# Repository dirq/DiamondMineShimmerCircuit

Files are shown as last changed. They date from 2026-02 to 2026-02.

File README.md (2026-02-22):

# Diamond Mine Shimmer Circuit — Final Design

A solar-charged, dusk-activated LED shimmer circuit. No microcontroller, no firmware —
pure analog CMOS logic and transistor drivers produce an organic, non-repeating sparkle
field that charges by day and shimmers by night.

## Documents

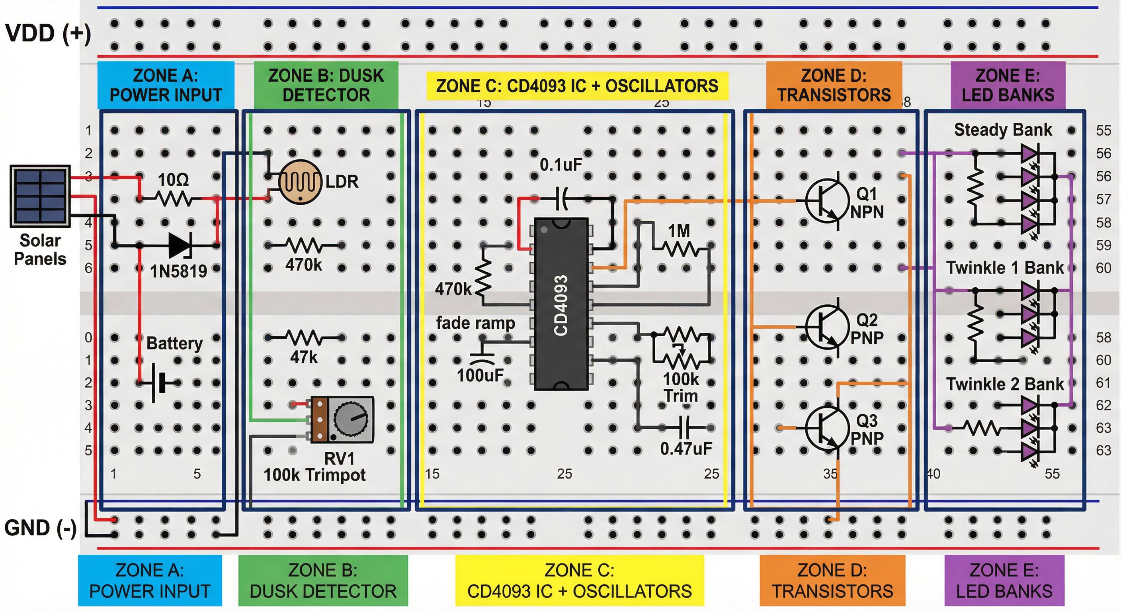
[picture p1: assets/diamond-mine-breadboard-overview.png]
Breadboard zone overview


| File | Contents |
|---|---|
| [BUILD-GUIDE.md](BUILD-GUIDE.md) | Step-by-step breadboard assembly and testing |
| [schematic.md](schematic.md) | Complete wiring schematic with gate assignments and net list |
| [bill-of-materials.md](bill-of-materials.md) | Full parts list with values, calculations, and cost |
| [breadboard-layout.md](breadboard-layout.md) | Physical layout with zone map and wire color guide |
| [circuit-evaluation.md](circuit-evaluation.md) | Performance characteristics and power budget |
| [circuit-evaluation-deep-dive.md](circuit-evaluation-deep-dive.md) | Extended design review with longevity analysis |
| [design-documentation.md](design-documentation.md) | Theory of operation, timing math, tuning guide |
| [bom.csv](bom.csv) | Machine-readable BOM for ordering |
| [diamond-mine-shimmer.cir](diamond-mine-shimmer.cir) | SPICE netlist for circuit simulation |
| [diamond-mine-shimmer.v](diamond-mine-shimmer.v) | Verilog behavioral model |
| [diamond-mine-shimmer.kicad_sch](diamond-mine-shimmer.kicad_sch) | KiCad schematic for PCB workflow |

## System Overview

```mermaid
graph TD
    subgraph Power
        SOLAR["Solar Panels<br/>5.5V, parallel"]
        RC["R_charge<br/>10 ohm"]
        D1["1N5819<br/>Schottky Diode"]
        BAT["3x AA NiMH<br/>3.6V nominal"]
        SOLAR -->|"charge"| RC --> D1 --> BAT
    end

    subgraph "CD4093 — Single IC, 4 Gates"
        G1["Gate 1<br/>Dusk Detector<br/>(pins 1,2 → 3)"]
        G2["Gate 2<br/>Oscillator 1 — Gated<br/>(pins 5,6 → 4)"]
        G3["Gate 3<br/>Oscillator 2 — Gated<br/>(pins 8,9 → 10)"]
        G4["Gate 4<br/>Unused — tied to VDD<br/>(pins 12,13 → 11)"]
    end

    subgraph Sensing
        LDR["LDR + Resistor<br/>Voltage Divider"]
        FADE["Fade-In Ramp<br/>470k + 100uF<br/>τ = 47s"]
    end

    subgraph "LED Outputs"
        Q1["Q1 (NPN 2N3904)<br/>Steady Bank<br/>3x LED @ 1.5k"]
        Q2["Q2 (PNP 2N3906)<br/>Twinkle Bank 1<br/>3x LED @ 2.2k"]
        Q3["Q3 (PNP 2N3906)<br/>Twinkle Bank 2<br/>3x LED @ 2.2k"]
    end

    BAT -->|"VDD"| G1
    BAT -->|"VDD"| G2
    BAT -->|"VDD"| G3
    LDR -->|"SENSE"| G1
    G1 -->|"DARK signal"| FADE
    G1 -->|"DARK gates pin 5"| G2
    G1 -->|"DARK gates pin 8"| G3
    FADE -->|"ramp voltage"| Q1
    G2 -->|"~2.6 Hz square wave"| Q2
    G3 -->|"~2.4 Hz square wave"| Q3
```

## Signal Flow at Dusk

```mermaid
sequenceDiagram
    participant Light as Ambient Light
    participant LDR as LDR Sensor
    participant G1 as Gate 1 (Dusk)
    participant Fade as Fade Ramp
    participant Osc as Oscillators
    participant LEDs as LED Field

    Light->>LDR: Light level drops
    LDR->>G1: SENSE voltage falls below VT-
    G1->>G1: Schmitt hysteresis prevents flicker
    G1->>Fade: DARK goes HIGH
    G1->>Osc: DARK enables Gate 2 and Gate 3
    Fade->>LEDs: Steady bank glows (10s to start, 40s full)
    Osc->>LEDs: Twinkle banks shimmer at ~2.4–2.6 Hz
    Note over LEDs: Beat frequency ~0.2 Hz creates<br/>drifting 5-second visual pattern
```

## Design Highlights

- **Solar self-sufficiency** — 5.5V panels with current-limited trickle charge
- **Smooth dusk activation** — Schmitt hysteresis prevents twilight flicker
- **Gentle 40-second fade-in** — RC ramp creates organic bloom
- **Multi-layer shimmer** — dual oscillator beats produce non-repeating patterns
- **Correct day/night gating** — PNP high-side switches ensure zero LED current in daylight
- **~5 mA active / ~7 uA standby** — months of battery life, easily solar-sustained
- **No microcontroller, no regulator, no firmware**

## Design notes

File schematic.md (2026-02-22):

# Wiring Schematic — Diamond Mine Shimmer

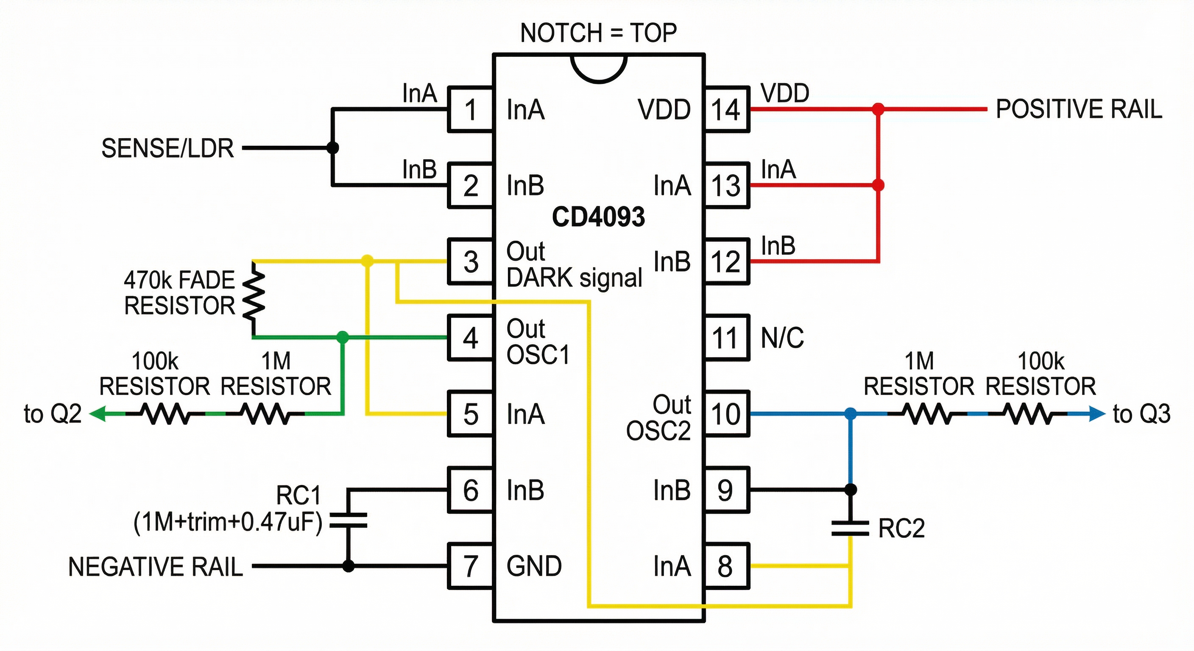
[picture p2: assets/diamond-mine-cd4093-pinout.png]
CD4093 pinout and connections


## CD4093 Pin Assignment

```
              ┌────∪────┐
Gate1 InA  1 ─┤         ├─ 14  VDD (+3.6V)
Gate1 InB  2 ─┤         ├─ 13  Gate4 InA (→ VDD)
Gate1 Out  3 ─┤  CD4093 ├─ 12  Gate4 InB (→ VDD)
Gate2 Out  4 ─┤         ├─ 11  Gate4 Out  (N/C)
Gate2 InA  5 ─┤         ├─ 10  Gate3 Out
Gate2 InB  6 ─┤         ├─  9  Gate3 InB
      GND  7 ─┤         ├─  8  Gate3 InA
              └─────────┘
```

```mermaid
graph TD
    subgraph "CD4093 Gate Assignments"
        direction LR
        G1["Gate 1 — Dusk Detector<br/>Pin 1 + Pin 2 → Pin 3<br/>(both inputs tied = inverter)"]
        G2["Gate 2 — Oscillator 1<br/>Pin 5 (DARK) + Pin 6 (RC) → Pin 4<br/>(gated oscillator)"]
        G3["Gate 3 — Oscillator 2<br/>Pin 8 (DARK) + Pin 9 (RC) → Pin 10<br/>(gated oscillator)"]
        G4["Gate 4 — Unused<br/>Pin 12 + Pin 13 → Pin 11<br/>(inputs tied to VDD)"]
    end
```

---

## Section A: Power and Charging

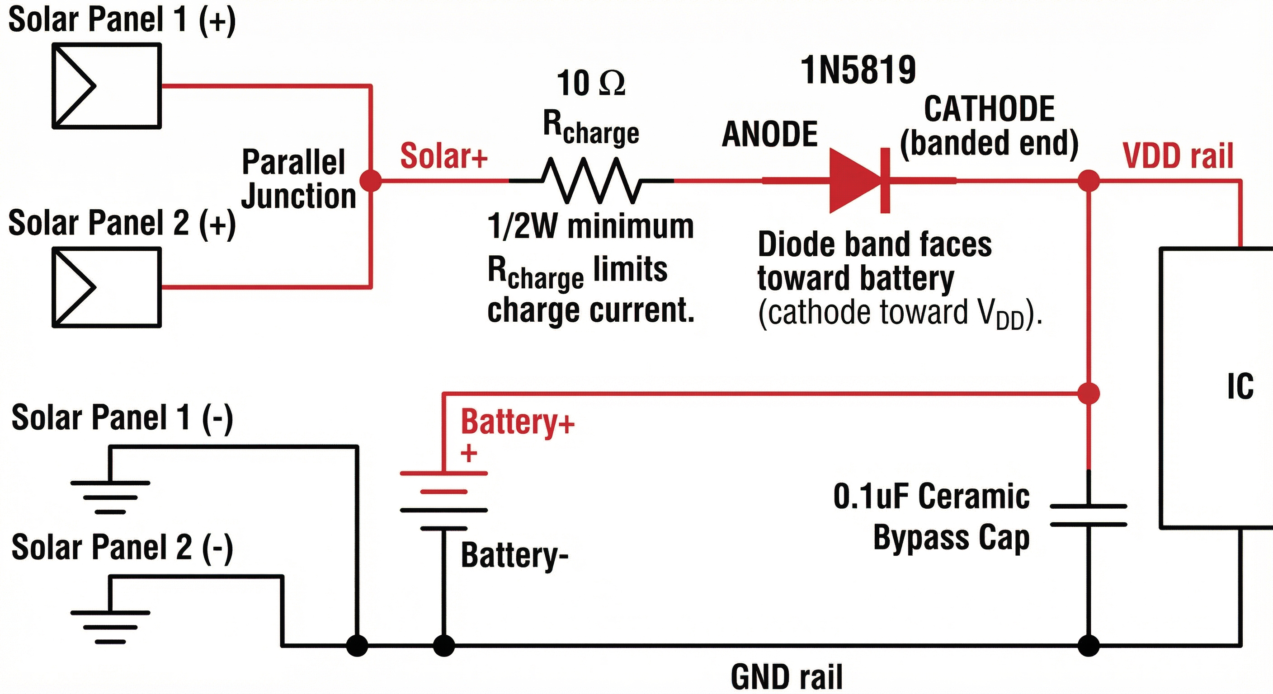
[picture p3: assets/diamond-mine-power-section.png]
Power section — solar, R_charge, diode, battery


```
    Solar+ ── R_charge (10Ω) ──┤>├──────── Battery+ (VDD)
                              1N5819
    Solar- ──────────────────────────────── Battery- (GND)

    Battery: 3x AA NiMH in series = 3.6V nominal
    Solar panels: 5.5V, 80–100 mA each, wired in parallel
    R_charge limits trickle current to safe NiMH range (85–220 mA)

    Bypass cap (close to IC pins):
    VDD (pin 14) ───┤├─── GND (pin 7)
                   0.1uF ceramic
```

```mermaid
graph LR
    S1["Solar Panel 1<br/>5.5V"] --> P["Parallel Junction"]
    S2["Solar Panel 2<br/>5.5V"] --> P
    P -->|"Solar+"| RC["R_charge<br/>10 ohm 1/2W"]
    RC --> D["1N5819<br/>Schottky"]
    D -->|"VDD"| B["+<br/>3x AA NiMH<br/>3.6V<br/>-"]
    B -->|"GND"| GND["System Ground"]
    D -->|"VDD"| C["0.1uF<br/>bypass"]
    C --> GND
```

---

## Section B: Dusk Detector (Gate 1)

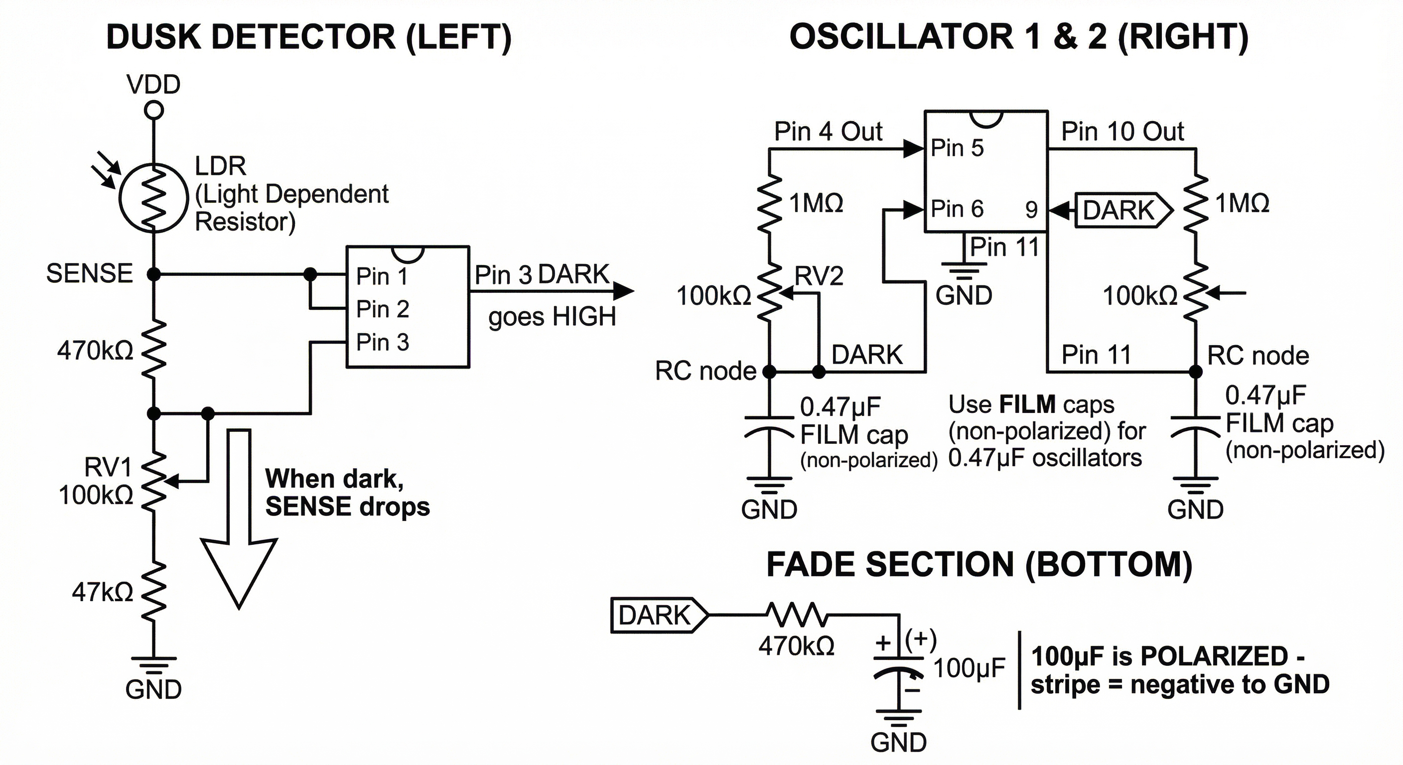
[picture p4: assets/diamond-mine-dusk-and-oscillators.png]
Dusk detector, fade ramp, and oscillator RC networks


```
    VDD ─── LDR ───┬─── Pin 1 (Gate1 InA)
                    │
                    ├─── Pin 2 (Gate1 InB)
                    │
                    └── 470k ──┬── 100k trimpot ── GND
                               │
                               └── 47k ── GND

    Pin 3 (Gate1 Out) = DARK signal
      Bright → LDR low-R → SENSE high → Output LOW  → LEDs OFF
      Dark   → LDR high-R → SENSE low → Output HIGH → LEDs ON
```

```mermaid
graph TD
    VDD["VDD (+3.6V)"] --> LDR["LDR<br/>(light dependent resistor)"]
    LDR --> SENSE["SENSE node"]
    SENSE --> P1["Pin 1"]
    SENSE --> P2["Pin 2"]
    SENSE --> R470["470k fixed"]
    R470 --> RNODE["Threshold junction"]
    RNODE --> TRIM["100k trimpot"]
    TRIM --> GND["GND"]
    RNODE --> R47["47k fixed"]
    R47 --> GND
    P1 --> G1["Gate 1 Output<br/>Pin 3"]
    P2 --> G1
    G1 --> DARK["DARK signal"]

    style DARK fill:#ffcc00,color:#000
```

---

## Section C: Fade-In Ramp

```
    Pin 3 (DARK) ── 470k ──┬── FADE node
                            │
                          100uF electrolytic
                            │
                           GND

    τ = 470k x 100uF = 47 seconds
    LEDs begin glowing at ~10s (Vbe threshold)
    Full brightness at ~40s
```

```mermaid
graph LR
    DARK["Pin 3<br/>DARK"] -->|"470k"| FADE["FADE node"]
    FADE -->|"100uF"| GND["GND"]
    FADE -->|"10k"| Q1B["Q1 Base<br/>(NPN Steady Bank)"]

    style DARK fill:#ffcc00,color:#000
    style FADE fill:#ff9944,color:#000
```

---

## Section D: Oscillator 1 — Gated (Gate 2)

```
    Pin 5 (Gate2 InA) ──── Pin 3 (DARK signal)     ← gating input

    Pin 4 (Gate2 Out) ── 1M ── 100k trimpot ──┬── Pin 6 (Gate2 InB)
                                               │
                                             0.47uF film
                                               │
                                              GND

    DARK=LOW  → Output stuck HIGH, no oscillation
               PNP transistor OFF → zero LED current
    DARK=HIGH → Oscillates at ~2.4–2.6 Hz (adjustable via trimpot)
               PNP transistor toggles → LEDs shimmer
```

---

## Section E: Oscillator 2 — Gated (Gate 3)

```
    Pin 8 (Gate3 InA) ──── Pin 3 (DARK signal)     ← gating input

    Pin 10 (Gate3 Out) ── 1M ── 100k trimpot ──┬── Pin 9 (Gate3 InB)
                                                │
                                              0.47uF film
                                                │
                                               GND

    Set trimpot to different position than Osc 1 for beat-frequency shimmer
```

```mermaid
graph TD
    DARK["DARK signal<br/>(Pin 3)"] --> P5["Pin 5<br/>(Gate 2 InA)"]
    DARK --> P8["Pin 8<br/>(Gate 3 InA)"]

    P4["Pin 4<br/>(Gate 2 Out)"] -->|"1M + 100k trim"| RC1["RC Node 1"]
    RC1 --> P6["Pin 6<br/>(Gate 2 InB)"]
    RC1 -->|"0.47uF"| GND1["GND"]
    P5 --- G2{"Gate 2"}
    P6 --- G2
    G2 --> P4

    P10["Pin 10<br/>(Gate 3 Out)"] -->|"1M + 100k trim"| RC2["RC Node 2"]
    RC2 --> P9["Pin 9<br/>(Gate 3 InB)"]
    RC2 -->|"0.47uF"| GND2["GND"]
    P8 --- G3{"Gate 3"}
    P9 --- G3
    G3 --> P10

    style DARK fill:#ffcc00,color:#000
```

**Frequency range with 1M fixed + 100k trimpot + 0.47uF:**

| Trimpot setting | Total R | Frequency | Character |
|---|---|---|---|
| 0 ohm (min) | 1.0M | 2.6 Hz | Quick shimmer |
| 50k (mid) | 1.05M | 2.5 Hz | Medium shimmer |
| 100k (max) | 1.1M | 2.4 Hz | Slightly slower |

---

## Section F: Unused Gate 4

```
    Pin 12 (Gate4 InA) ──── VDD
    Pin 13 (Gate4 InB) ──── VDD
    Pin 11 (Gate4 Out)      no connection
```

Floating CMOS inputs draw excess current and risk latch-up. Always tie unused
inputs to a rail.

---

## Section G: LED Drivers

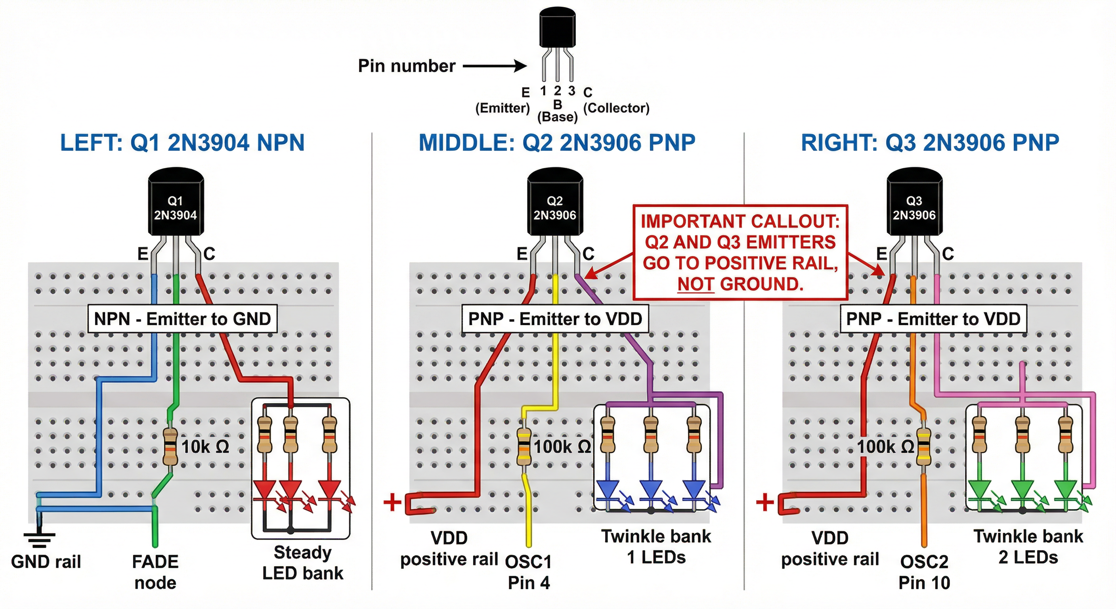
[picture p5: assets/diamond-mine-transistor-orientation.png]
Transistor orientation — E-B-C pin order, NPN vs PNP


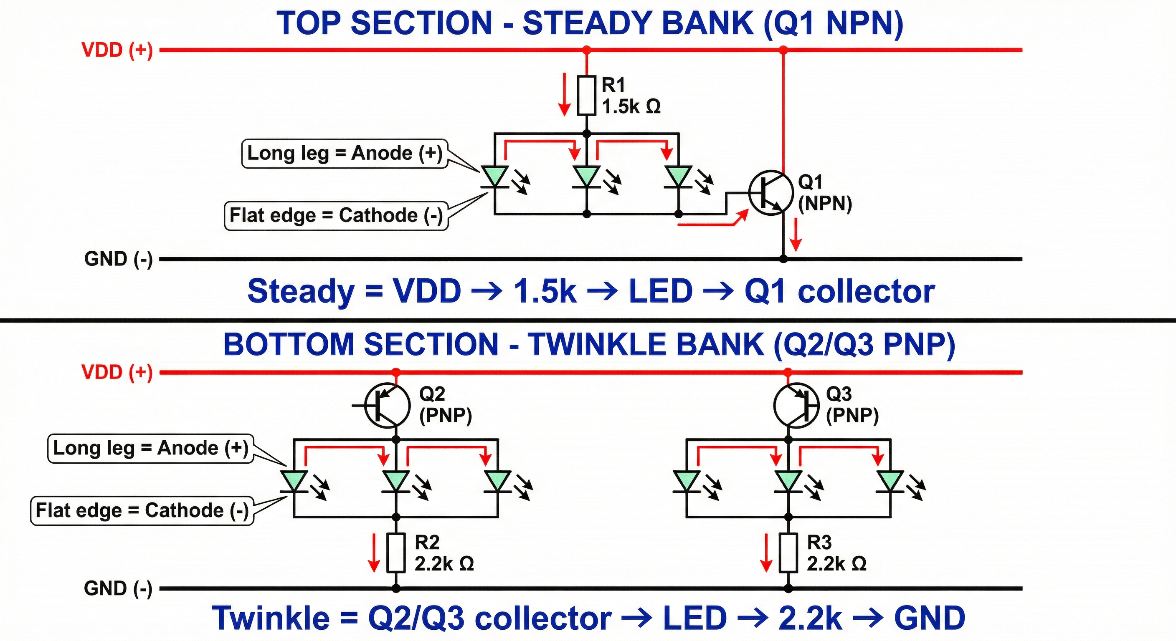
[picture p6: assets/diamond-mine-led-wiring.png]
LED wiring — Steady bank vs Twinkle bank topology


### Steady Bank — Q1 (NPN 2N3904, low-side switch, fade-controlled)

```
    FADE node ── 10k ──── Q1 Base (2N3904 NPN)
                          Q1 Emitter ── GND
                          Q1 Collector ──┬── LED1 cathode ── LED1 anode ── 1.5k ── VDD
                                         ├── LED2 cathode ── LED2 anode ── 1.5k ── VDD
                                         └── LED3 cathode ── LED3 anode ── 1.5k ── VDD
```

Day: FADE = 0V → Q1 OFF → LEDs dark
Night: FADE ramps 0V → 3.6V over 47s → Q1 gradually turns on → LEDs bloom

### Twinkle Bank 1 — Q2 (PNP 2N3906, high-side switch)

```
                          VDD
                           │
                       Q2 Emitter (2N3906 PNP)
                           │
    Pin 4 (OSC1) ── 100k ── Q2 Base
                           │
                       Q2 Collector ──┬── LED anode ── LED cathode ── 2.2k ── GND
                                      ├── LED anode ── LED cathode ── 2.2k ── GND
                                      └── LED anode ── LED cathode ── 2.2k ── GND
```

Day: Pin 4 = HIGH (stuck) → Q2 base ≈ VDD → Veb ≈ 0 → Q2 OFF → LEDs dark
Night: Pin 4 oscillates → Q2 toggles → LEDs shimmer

### Twinkle Bank 2 — Q3 (PNP 2N3906, high-side switch)

```
                          VDD
                           │
                       Q3 Emitter (2N3906 PNP)
                           │
    Pin 10 (OSC2) ── 100k ── Q3 Base
                           │
                       Q3 Collector ──┬── LED anode ── LED cathode ── 2.2k ── GND
                                      ├── LED anode ── LED cathode ── 2.2k ── GND
                                      └── LED anode ── LED cathode ── 2.2k ── GND
```

```mermaid
graph TD
    VDD["VDD (+3.6V)"]

    VDD -->|"1.5k"| SL1["LED"] --> Q1C["Q1 Collector"]
    VDD -->|"1.5k"| SL2["LED"] --> Q1C
    VDD -->|"1.5k"| SL3["LED"] --> Q1C
    FADE["FADE node"] -->|"10k"| Q1B["Q1 Base"]
    Q1B --> Q1["Q1 NPN<br/>2N3904"]
    Q1C --> Q1
    Q1 --> GND1["GND"]

    VDD --> Q2E["Q2 Emitter"]
    Q2E --> Q2["Q2 PNP<br/>2N3906"]
    OSC1["Pin 4<br/>OSC1"] -->|"100k"| Q2B["Q2 Base"]
    Q2B --> Q2
    Q2 --> Q2C["Q2 Collector"]
    Q2C --> TL1["LED"] -->|"2.2k"| GND2["GND"]
    Q2C --> TL2["LED"] -->|"2.2k"| GND2
    Q2C --> TL3["LED"] -->|"2.2k"| GND2

    VDD --> Q3E["Q3 Emitter"]
    Q3E --> Q3["Q3 PNP<br/>2N3906"]
    OSC2["Pin 10<br/>OSC2"] -->|"100k"| Q3B["Q3 Base"]
    Q3B --> Q3
    Q3 --> Q3C["Q3 Collector"]
    Q3C --> TL4["LED"] -->|"2.2k"| GND3["GND"]
    Q3C --> TL5["LED"] -->|"2.2k"| GND3
    Q3C --> TL6["LED"] -->|"2.2k"| GND3

    style FADE fill:#ff9944,color:#000
    style OSC1 fill:#44cc44,color:#000
    style OSC2 fill:#4488ff,color:#fff
```

---

## Complete Net List

| Net Name | Connections |
|---|---|
| **VDD** | Battery+, R_charge output, Pin 14, Pin 12, Pin 13, LDR leg 1, Steady LED anode resistors, Q2 emitter, Q3 emitter, 0.1uF cap |
| **GND** | Battery-, Pin 7, Trimpot/47k ground ends, 100uF(-), 0.47uF(x2), Q1 emitter, Twinkle LED cathode resistors, 0.1uF cap |
| **SOLAR+** | Solar panel positive bus, R_charge input |
| **CHARGE** | R_charge output, 1N5819 anode |
| **SENSE** | LDR leg 2, Pin 1, Pin 2, 470k top |
| **THRESH** | 470k bottom, 100k trimpot wiper/end1, 47k top |
| **DARK** | Pin 3, Pin 5, Pin 8, 470k fade top |
| **FADE** | 470k fade bottom, 100uF(+), 10k top |
| **RC1** | 1M+trim/0.47uF junction (osc 1), Pin 6 |
| **RC2** | 1M+trim/0.47uF junction (osc 2), Pin 9 |
| **OSC1** | Pin 4, 1M top (to RC1), 100k (to Q2 base) |
| **OSC2** | Pin 10, 1M top (to RC2), 100k (to Q3 base) |
| **Q1_COL** | Q1 collector, Steady LED cathodes (3x) |
| **Q2_COL** | Q2 collector, Twinkle 1 LED anodes (3x) |
| **Q3_COL** | Q3 collector, Twinkle 2 LED anodes (3x) |

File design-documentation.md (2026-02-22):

# Design Documentation — Diamond Mine Shimmer Circuit

## 1. Design Philosophy

The goal is a self-sustaining "bioluminescent cave" — something that feels alive
without any digital intelligence. Every design choice serves this:

- **No microcontroller**: Analog randomness is inherently organic. Two free-running
  oscillators with irrational frequency ratios produce quasi-random patterns that
  never exactly repeat.
- **Solar + NiMH**: The circuit runs itself indefinitely with zero user intervention.
- **CMOS logic at 3.6V**: The CD4093 operates down to 3V with nanoamp-level
  quiescent current — perfect for battery life.
- **Schmitt-trigger hysteresis**: Prevents chatter at the dusk/dawn boundary and
  creates clean oscillator waveforms.
- **PNP high-side twinkle switches**: Ensures zero LED current during daytime when
  the NAND gate outputs are stuck HIGH.

---

## 2. Power System

### 2.1 Solar Charging

```
Solar Panels (5.5V, parallel) ── R_charge (10Ω) ──►|── 3×AA NiMH (3.6V)
                                                   1N5819
```

**Why 5.5V panels?** The battery pack reaches 4.35V when fully charged. Adding
the Schottky drop (0.3V), the solar source must exceed 4.65V. Panels rated at
5.5V provide adequate headroom across all conditions.

**Why parallel wiring?** Parallel panels produce the same voltage at combined
current. Series wiring would give 11V — far too high for direct NiMH charging
without a regulator.

**Why R_charge (10 ohm)?** Without current limiting, a fully discharged battery
could draw the panel's full short-circuit current. The resistor self-tapers
the charge rate:

| Battery State | Voltage | Charge Current | Rate |
|---|---|---|---|
| Deeply discharged | 3.0V | 220 mA | C/9 |
| Nominal | 3.6V | 160 mA | C/12.5 |
| Near full | 4.0V | 120 mA | C/17 |
| Fully charged | 4.35V | 85 mA | C/24 |

NiMH cells safely tolerate indefinite trickle at C/10 or below. The resistor
keeps the circuit in the safe zone for all practical conditions.

**Why Schottky?** At night, solar panels become low-impedance paths to ground.
Without D1, the battery discharges backward through the panels. A standard
silicon diode (1N4001) drops ~0.6V — at 3.6V that is a 17% loss. The 1N5819
Schottky drops only ~0.3V.

**Why NiMH?** NiMH cells tolerate continuous trickle charging without a charge
controller (unlike Li-ion). At the C/24 rates typical of this design at full
charge, they charge safely and indefinitely. Eneloop cells provide 2100-cycle
life and <15% self-discharge over 6 months.

### 2.2 Battery Sizing

Three NiMH cells give 3.6V nominal (3.0V discharged, 4.35V freshly charged).
This keeps the CD4093 comfortably in its 3–18V operating range and provides
enough headroom above red/amber LED forward voltage (~1.8–2.1V).

---

## 3. Dusk Detector

```
VDD ──── [LDR] ──── SENSE ──┬── [470k] ──┬── [100k trimpot] ── GND
                             │            └── [47k] ── GND
                        CD4093 Gate 1
                        (pins 1+2 tied)
```

### 3.1 Voltage Divider Behavior

| Condition | LDR Resistance | SENSE Voltage | Gate 1 Output |
|---|---|---|---|
| Bright light | ~5–10 kΩ | High (~VDD) | LOW (disabled) |
| Dim indoor | ~100–500 kΩ | Mid | Depends on trimpot |
| Darkness | ~500 kΩ–2 MΩ | Low (~GND) | HIGH (enabled) |

### 3.2 Pull-Down Network

The three-element pull-down (470k fixed + 100k trimpot || 47k) provides:

With trimpot at 0Ω: pull-down = 470k + (0 || 47k) = 470k
With trimpot at 100k: pull-down = 470k + (100k || 47k) = 470k + 32k = 502k

The trimpot provides fine adjustment (~7% range) rather than coarse control.
This is appropriate for a set-once installation.

### 3.3 Schmitt-Trigger Advantage

The CD4093 has built-in hysteresis (~30% of VDD). At 3.6V:
- Upper threshold (VT+): ~2.4V
- Lower threshold (VT-): ~1.2V
- Hysteresis band: ~1.2V

This prevents rapid on/off cycling during gradual dusk transitions. The SENSE
voltage must cross VT- (falling) to turn LEDs on, and VT+ (rising) to turn
them off. The ~1.2V gap means the LDR must change by hundreds of kilohms
between the two states — ensuring clean, single transitions.

---

## 4. Fade-In Ramp

```
DARK (HIGH) ──── [470kΩ] ──── FADE ──┬──── [100µF] ──── GND
                                      │
                                      └── [10k] → Q1 base
```

### 4.1 RC Time Constant

```
τ = R × C = 470,000 Ω × 0.0001 F = 47 seconds
```

### 4.2 Voltage Profile

```
V_FADE(t) = V_DARK × (1 - e^(-t/τ))
```

| Time | V_FADE | % of V_DARK | Perceived Effect |
|---|---|---|---|
| 0 s | 0.00V | 0% | LEDs off |
| 10 s | 0.72V | 19% | First hint of glow (Vbe threshold) |
| 20 s | 1.21V | 34% | Visible dim glow |
| 47 s | 2.27V | 63% | Moderate brightness (1τ) |
| 94 s | 3.10V | 86% | Near full (2τ) |
| 141 s | 3.42V | 95% | Essentially full (3τ) |

Q1 operates in its active (linear) region during the ramp, so LED current
rises proportionally with V_FADE. The visual effect is a smooth, organic bloom.

### 4.3 Dawn Fade-Out

When DARK goes LOW at dawn:
1. The 100uF cap discharges through 10k into Q1 base (τ = 1s) while Q1 conducts
2. LEDs fade out in ~2–3 seconds
3. Below Vbe (~0.7V), Q1 turns off and remaining charge bleeds through 470k

The fade-out is fast but not jarring — an appropriate "lights going to sleep"
transition.

### 4.4 Modification Options

| Desired Fade Time | R_fade | τ (seconds) | 95% Time |
|---|---|---|---|
| Quick (10 s) | 100 kΩ | 10 s | ~30 s |
| Medium (47 s) | 470 kΩ | 47 s | ~2.5 min |
| Slow (100 s) | 1 MΩ | 100 s | ~5 min |
| Very slow (220 s) | 2.2 MΩ | 220 s | ~11 min |

---

## 5. Schmitt-Trigger Oscillators

Each oscillator is a classic CD4093 relaxation oscillator with gating:

```
    DARK ──── Pin 5 (Gate 2 InA)         ← gating input

         ┌──── [R_osc (1MΩ + Trim)] ────┐
         │                                │
    Pin 6 (InB) ──────────────── Pin 4 (Out)
         │
      [C_osc 0.47µF]
         │
        GND
```

### 5.1 How It Works

1. When DARK = HIGH, the gate acts as an inverter on Pin 6.
2. Capacitor charges through R_osc toward VDD.
3. When voltage crosses the **upper Schmitt threshold** (~2.4V), the output snaps LOW.
4. Capacitor discharges through R_osc toward GND.
5. When voltage crosses the **lower Schmitt threshold** (~1.2V), the output snaps HIGH.
6. Cycle repeats.

When DARK = LOW, the NAND output is stuck HIGH regardless of Pin 6. No
oscillation occurs.

### 5.2 Frequency Formula

```
f ≈ 1 / (1.2 × R × C)
```

For R = 1.05MΩ (1M + 50k trim) and C = 0.47µF:
```
f ≈ 1 / (1.2 × 1,050,000 × 0.00000047)
f ≈ 1 / 0.592
f ≈ 1.69 Hz  (theoretical)
```

Actual frequency is typically 2.4–2.6 Hz due to Schmitt threshold ratios differing
from the 1.2x approximation at low VDD. The trimpot allows fine adjustment.

### 5.3 Frequency Range

| Trimpot Setting | Total R | Frequency | Character |
|---|---|---|---|
| 0 ohm (min) | 1.0M | ~2.6 Hz | Quick shimmer |
| 50k (mid) | 1.05M | ~2.5 Hz | Medium shimmer |
| 100k (max) | 1.1M | ~2.4 Hz | Slightly slower |

### 5.4 The Shimmer Effect

The magic happens because the two oscillators run at **slightly different
frequencies**. If Osc 1 runs at 2.6 Hz and Osc 2 at 2.4 Hz, the beat frequency is:

```
f_beat = |f1 - f2| = |2.6 - 2.4| = 0.2 Hz → 5-second drift cycle
```

The steady-glow bank provides a constant "floor" while the two twinkle banks
create overlapping shimmer. Together, the three layers produce a complex,
organic light field:

```
Brightness
    ▲
    │   ╱╲   ╱╲   ╱╲   ╱╲       ← Twinkle Bank 1 (~2.6 Hz)
    │  ╱  ╲ ╱  ╲ ╱  ╲ ╱  ╲
    │──────────────────────────  ← Steady Glow (base)
    │    ╱╲  ╱╲  ╱╲  ╱╲
    │   ╱  ╲╱  ╲╱  ╲╱  ╲       ← Twinkle Bank 2 (~2.4 Hz)
    │
    └──────────────────────────► Time
           ↕ 5s beat cycle ↕
```

---

## 6. LED Driver Design

### 6.1 Q1: Steady Bank (NPN 2N3904, Low-Side)

```
VDD ──── [1.5k] ──── LED ──── Q1 Collector
                               Q1 Emitter ── GND
FADE ──── [10k] ──── Q1 Base
```

During fade-in, Q1 operates in its **active region** — collector current rises
proportionally with base voltage. Once V_FADE reaches full VDD, Q1 saturates and
LED current is limited by the 1.5k resistor:

```
I_LED = (VDD - V_LED - Vce_sat) / R = (3.6 - 2.0 - 0.2) / 1500 = 0.93 mA
```

### 6.2 Q2/Q3: Twinkle Banks (PNP 2N3906, High-Side)

```
                   VDD
                    │
                Q2 Emitter (PNP)
                    │
OSC1 ── [100k] ── Q2 Base
                    │
                Q2 Collector
                    │
                   LED
                    │
                  [2.2k]
                    │
                   GND
```

**Why PNP high-side?** The oscillator NAND gates output HIGH when DARK = LOW
(daytime). With NPN low-side switches, this HIGH would turn the transistors ON —
keeping twinkle LEDs lit during the day. PNP transistors turn OFF when their
base is at VDD (HIGH), solving this naturally:

| Oscillator Output | PNP Base | PNP State | LEDs |
|---|---|---|---|
| HIGH (day, stuck) | ≈ VDD | OFF (Veb ≈ 0) | Dark |
| HIGH (night, osc) | ≈ VDD | OFF | Dark |
| LOW (night, osc) | ≈ 0V | ON (Veb ≈ VDD) | Lit |

Base drive through 100k ensures reliable saturation for 3 LEDs per bank:
```
Ib = (VDD - Vbe) / 100k = (3.6 - 0.7) / 100k = 29 uA
Ic_max = hFE × Ib = 100 × 29 uA = 2.9 mA (> 1.92 mA needed)
```

LED current when ON:
```
I_LED = (VDD - Vce_sat - V_LED) / R = (3.6 - 0.2 - 2.0) / 2200 = 0.64 mA
```

### 6.3 Why Individual LED Resistors?

Each LED has manufacturing variations in forward voltage (±0.2V typical). With
a shared resistor, the lowest-Vf LED hogs current while others go dim. Individual
resistors ensure equal current sharing — critical for visual uniformity in the
"diamond field."

---

## 7. Component Selection Rationale

### CD4093 (not CD4011)

The Schmitt-trigger inputs provide:
1. **Clean oscillation** — defined thresholds prevent erratic behavior
2. **Noise immunity** — ~1.2V hysteresis rejects power supply ripple
3. **Reliable dusk switching** — clean snap despite slowly-changing LDR voltage

### 2N3906 PNP (not 2N3904 NPN) for Twinkle Banks

NAND gate with one LOW input gives HIGH output. For zero daytime current:
- NPN + HIGH output = ON (wrong)
- PNP + HIGH output = OFF (correct)

### Film Capacitors (not ceramic) for Oscillators

Film capacitors have:
- Tight tolerance (±5% vs ±20% for ceramic)
- Zero piezoelectric effect
- Excellent long-term stability
- Negligible leakage

For timing, this means twinkle rate stays consistent over temperature and years.

### Red/Amber LEDs (not white/blue)

At 3.6V supply with 2.2k resistors:
- Red/amber (Vf ~2.0V): I = (3.6-0.2-2.0)/2200 = 0.64 mA (bright enough)
- White/blue (Vf ~3.0V): I = (3.6-0.2-3.0)/2200 = 0.18 mA (very dim)

Red and amber also evoke the warm "crystal mine" aesthetic.

---

## 8. Power Budget

### 8.1 Standby (Daytime)

| Component | Current |
|---|---|
| CD4093 quiescent (static) | ~0.005 µA |
| LDR divider (bright: ~5k + ~500k) | ~7 µA |
| Q1 OFF (FADE = 0V) | 0 |
| Q2/Q3 OFF (PNP, base HIGH) | 0 |
| **Total standby** | **~7 µA** |

### 8.2 Active (Nighttime)

| Component | Current |
|---|---|
| CD4093 + oscillators (dynamic) | ~0.1 mA |
| LDR divider (dark) | ~2.4 µA |
| Steady bank: 3 × 0.93 mA | 2.79 mA |
| Twinkle 1: 3 × 0.64 mA × 50% | 0.96 mA |
| Twinkle 2: 3 × 0.64 mA × 50% | 0.96 mA |
| Q1 base drive | 0.29 mA |
| Q2/Q3 base drive | 0.06 mA |
| **Total active (average)** | **~5.1 mA** |
| **Total active (peak)** | **~7.0 mA** |

### 8.3 Battery Life

```
Without solar:
  Continuous: 2000 / 5.1 = 392 hours ≈ 16.3 days
  10 hrs/night: 39 nights

With solar (2 panels, 4 hrs sun):
  Daily charge: 200 mA × 4 hrs = 800 mAh
  Daily discharge: 5.1 mA × 10 hrs = 51 mAh
  Net surplus: +749 mAh/day → battery stays full indefinitely
```

---

## 9. Tuning Guide

### 9.1 Dusk Sensitivity (RV1)

Turn the 100k dusk trimpot:
- **Clockwise** (more resistance): triggers at slightly less darkness
- **Counter-clockwise** (less resistance): requires deeper darkness

Test by slowly covering the LDR and observing when the DARK signal goes HIGH
(measure Pin 3 with a multimeter).

### 9.2 Twinkle Rates (RV2, RV3)

Set each oscillator's trimpot to a different position:
- Both at similar settings: synchronized flashing (less interesting)
- Slightly different: slow beat pattern (optimal shimmer)
- Very different: fast, complex pattern

**Recommended starting point:** RV2 at 30%, RV3 at 70%. This gives a beat
period of about 5 seconds — a gentle, natural-feeling drift.

### 9.3 Fade Speed

The fade-in time is set by R_fade (470k) and C_fade (100uF). To change:
- Faster: replace R_fade with 220k (τ ≈ 22s)
- Slower: replace R_fade with 1M (τ ≈ 100s)

### 9.4 LED Brightness

| Change | Method | Effect |
|---|---|---|
| Brighter steady | Reduce 1.5k to 680Ω | ~2.1 mA per LED |
| Dimmer steady | Increase 1.5k to 3.3k | ~0.42 mA per LED |
| Brighter twinkle | Reduce 2.2k to 1k | ~1.4 mA per LED |
| Dimmer twinkle | Increase 2.2k to 4.7k | ~0.30 mA per LED |
| More LEDs | Add LEDs to any bank | Scale resistor count to match |
| Mixed colors | Use different Vf LEDs | Adjust resistors per-LED for equal brightness |

---

## 10. Advanced Modifications

### 10.1 Third Oscillator (Gate 4)

Gate 4 is currently unused. Wire it as a third oscillator for an additional
shimmer layer:

- **Slow breathing (0.2 Hz):** 1M + 2.2µF → drives another PNP + LED cluster
- **Fast glitter (8–10 Hz):** 220k + 0.47µF → subtle high-speed sparkle overlay

### 10.2 PWM Dimming via Gate Mixing

Use Gate 4 as an AND/OR combiner of the two oscillator outputs. The resulting
complex waveform drives a single LED bank through a PNP transistor, creating
pulse patterns impossible with a single oscillator.

### 10.3 Solar Panel Voltage Indicator

Add a single LED + 100kΩ from the solar panel positive (before R_charge) to
GND. It glows faintly during daylight to confirm panels are producing power.
Current: (5.5 - 2.0) / 100k = 35µA — negligible impact on charging.

### 10.4 Under-Voltage Lockout

For extra NiMH protection, add a TL431 or MAX809 voltage supervisor ($0.50)
that disables the circuit below 3.0V. This prevents deep discharge damage
during extended cloudy periods.

---

## 11. References

- CD4093 datasheet: [Texas Instruments CD4093B](https://www.ti.com/product/CD4093B)
- 2N3904 datasheet: [ON Semiconductor 2N3904](https://www.onsemi.com/pdf/datasheet/2n3904-d.pdf)
- 2N3906 datasheet: [ON Semiconductor 2N3906](https://www.onsemi.com/pdf/datasheet/2n3906-d.pdf)
- 1N5819 datasheet: [Vishay 1N5819](https://www.vishay.com/docs/88526/1n5819.pdf)
- NiMH charging guide: [Battery University — NiMH](https://batteryuniversity.com/article/bu-407-charging-nickel-metal-hydride)

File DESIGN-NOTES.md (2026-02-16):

# Design Notes

> Circuit theory, timing math, and tuning guidance for the Diamond Mine Shimmer Circuit.

---

## Design Philosophy

The goal is a self-sustaining "bioluminescent cave" — something that feels alive without any digital intelligence. Every design choice serves this:

- **No microcontroller**: Analog randomness is inherently organic. Two free-running oscillators with irrational frequency ratios produce quasi-random patterns that never exactly repeat.
- **Solar + NiMH**: The circuit runs itself indefinitely with zero user intervention.
- **CMOS logic at 3.6 V**: The CD4093 operates down to 3 V with nanoamp-level quiescent current — perfect for battery life.
- **Schmitt-trigger hysteresis**: Prevents chatter at the dusk/dawn boundary and creates clean oscillator waveforms.

---

## Circuit Theory

### 1. Power System

```
Solar Panels (parallel) ──►|── 3×AA NiMH (3.6 V nominal)
                          1N5819
```

**Why Schottky?** At night, the solar panels become a low-impedance path to ground. Without D1, the battery would discharge backward through the panels. A standard silicon diode (1N4001) drops ~0.6 V — at 3.6 V that is a 17% loss. The 1N5819 Schottky drops only ~0.2 V, leaving more voltage for the circuit.

**Why NiMH?** NiMH cells are tolerant of continuous trickle charging (unlike Li-ion, which requires a charge controller). Keep sustained charge current conservative (about C/25 to C/20 for long life), and size panel current accordingly.

**Why 3 cells?** Three NiMH cells give 3.6 V nominal (3.0 V discharged → 4.2 V freshly charged). This keeps the CD4093 comfortably in its 3–15 V operating range and provides enough headroom above the LED forward voltage (~2.8 V for warm white).

---

### 2. Dusk Detector

```
VDD ──── [LDR] ──── SENSE ──── [500k Pot] ──── GND
                       │
                    CD4093 Gate 1
                    (pins 1+2 tied)
```

**Voltage divider behavior:**

| Condition | LDR Resistance | SENSE Voltage | Gate 1 Output |
|---|---|---|---|
| Bright light | ~10 kΩ | High (~VDD) | LOW (disabled) |
| Darkness | ~1 MΩ+ | Low (~GND) | HIGH (enabled) |

The 500 kΩ potentiometer sets the trip point. Turn clockwise → more sensitive (triggers at higher ambient light). Turn counterclockwise → less sensitive (requires deeper darkness).

**Schmitt-trigger advantage:** The CD4093 has built-in hysteresis (~30% of VDD). At 3.6 V:
- Upper threshold: ~2.4 V
- Lower threshold: ~1.2 V
- Hysteresis band: ~1.2 V

This prevents rapid on/off cycling during gradual dusk transitions.

---

### 3. Fade-In Ramp

```
DARK (HIGH) ──── [470kΩ] ──── FADE ──┬──── [100µF] ──── GND
                                      │
                                      └── Q1 base resistor
```

**RC time constant:**

```
τ = R × C = 470,000 Ω × 0.0001 F = 47 seconds
```

**Voltage at time t:**

```
V_FADE(t) = V_DARK × (1 - e^(-t/τ))
```

| Time | V_FADE | % of V_DARK | Perceived Effect |
|---|---|---|---|
| 0 s | 0.00 V | 0% | LEDs off |
| 10 s | 0.72 V | 19% | First hint of glow |
| 20 s | 1.21 V | 34% | Visible dim glow |
| 47 s | 2.27 V | 63% | Moderate brightness |
| 94 s | 3.10 V | 86% | Near full |
| 141 s | 3.42 V | 95% | Essentially full |

The Q1 transistor operates in its active (linear) region during the ramp, so LED current rises proportionally with V_FADE. The visual effect is a smooth, organic bloom.

**Modification options:**

| Desired Fade Time | R_fade | τ (seconds) | 95% Time |
|---|---|---|---|
| Quick (10 s) | 100 kΩ | 10 s | ~30 s |
| Medium (47 s) | 470 kΩ | 47 s | ~2.5 min |
| Slow (100 s) | 1 MΩ | 100 s | ~5 min |
| Very slow (220 s) | 2.2 MΩ | 220 s | ~11 min |

---

### 4. Schmitt-Trigger Oscillators

Each oscillator is a classic CD4093 relaxation oscillator:

```
         ┌──── [R_osc (1MΩ + Trim)] ────┐
         │                                │
Input ───┤                         Output (Y)
         │
      [C_osc 0.47µF]
         │
        GND
```

**How it works:**

1. Capacitor charges through R_osc toward VDD.
2. When voltage crosses the **upper Schmitt threshold** (~2.4 V), the gate output snaps LOW.
3. Capacitor now discharges through R_osc toward GND.
4. When voltage crosses the **lower Schmitt threshold** (~1.2 V), the gate output snaps HIGH.
5. Cycle repeats.

**Frequency formula:**

```
f ≈ 1 / (1.2 × R × C)
```

For R = 1 MΩ and C = 0.47 µF:

```
f ≈ 1 / (1.2 × 1,000,000 × 0.00000047)
f ≈ 1 / 0.564
f ≈ 1.77 Hz
```

**Output waveform:** Asymmetric square wave (~50% duty cycle). The LED bank blinks on and off at this rate.

---

### 5. Creating the "Shimmer" Effect

The magic happens because the two oscillators run at **slightly different frequencies**. If Osc 1 runs at 1.77 Hz and Osc 2 at 1.60 Hz, the difference is 0.17 Hz — meaning the two patterns drift in and out of sync over a ~6-second cycle.

**Beat frequency:**

```
f_beat = |f1 - f2|
```

| Osc 1 | Osc 2 | Beat Period | Visual Effect |
|---|---|---|---|
| 1.77 Hz | 1.60 Hz | ~5.9 s | Moderate drift |
| 1.77 Hz | 1.70 Hz | ~14.3 s | Slow, subtle drift |
| 1.77 Hz | 1.50 Hz | ~3.7 s | Faster, more dynamic |

The steady-glow bank (driven by the fade ramp) provides a constant "floor" while the two twinkle banks create overlapping shimmer. Together, the three layers produce a complex, organic light field:

```
Brightness
    ▲
    │   ╱╲   ╱╲   ╱╲   ╱╲       ← Twinkle Bank 1
    │  ╱  ╲ ╱  ╲ ╱  ╲ ╱  ╲
    │──────────────────────────  ← Steady Glow (base)
    │    ╱╲  ╱╲  ╱╲  ╱╲
    │   ╱  ╲╱  ╲╱  ╲╱  ╲       ← Twinkle Bank 2
    │
    └──────────────────────────► Time
```

---

### 6. LED Driver Analysis

Each transistor stage is a common-emitter switch/amplifier:

```
VDD ──── [R_LED] ──── LED ──── Collector
                                  │
                               2N3904
                                  │
                               Emitter ──── GND

Signal ──── [R_base] ──── Base
```

**Q1 (Steady driver) — linear mode during fade:**

During the fade-in ramp, V_FADE rises from 0 → VDD over ~47 s. Q1 operates in its active region, so collector current (and LED brightness) increases smoothly:

```
I_C ≈ (V_FADE - V_BE) / R_base × h_FE    (active region)
```

Once V_FADE reaches full VDD, Q1 saturates and the LED current is limited by R_LED:

```
I_LED = (VDD - V_LED - V_CE(sat)) / R_LED
      = (3.6 - 2.8 - 0.2) / 1500
      ≈ 0.4 mA per LED
```

**Q2 / Q3 (Twinkle drivers) — switching mode:**

The oscillator outputs are square waves, so Q2 and Q3 switch fully on and off. Current per LED while ON:

```
I_LED = (VDD - V_LED - V_CE(sat)) / R_LED
      = (3.6 - 2.8 - 0.2) / 2200
      ≈ 0.27 mA per LED
```

**Daylight lockout:** each twinkle base includes a clamp diode to DARK (`anode=base`, `cathode=DARK`). In daylight (`DARK=LOW`), any oscillator-high base drive is shunted away so the twinkle transistors remain off.

---

## Component Selection Rationale

### Why CD4093 and not CD4011 (non-Schmitt NAND)?

The Schmitt-trigger inputs provide:
1. **Clean oscillation** — defined thresholds prevent erratic behavior near transitions
2. **Noise immunity** — the ~1.2 V hysteresis band rejects power supply ripple and coupled noise
3. **Reliable dusk switching** — the LDR voltage changes slowly; Schmitt inputs give a clean snap

### Why NPN common-emitter and not direct IC drive?

The CD4093 output can source/sink only ~1 mA at 3.6 V. With multiple LEDs per bank, a transistor buffer is essential. The 2N3904 easily handles 50+ mA, far beyond what we need.

### Why individual LED resistors and not shared?

Each LED has manufacturing variations in forward voltage. Individual resistors ensure equal current sharing. Shared resistors would cause the lowest-V_F LED to hog current while others stay dim.

### Why 0.47 µF film caps for oscillators?

Film capacitors have:
- Tight tolerance (±5% typical vs ±20% for ceramic)
- Zero piezoelectric effect (ceramic caps change value with vibration)
- Excellent long-term stability
- Negligible leakage

For timing applications, this means your twinkle rate stays consistent over temperature and time.

---

## Advanced Modifications

### Mixed LED Colors

Replace some warm white LEDs with:
- **Amber** (V_F ≈ 2.0 V) — adjust resistors to compensate for lower forward voltage
- **Cool white** (V_F ≈ 3.0 V) — may need lower resistors for similar brightness
- **UV** (V_F ≈ 3.2 V) — near the voltage limit; works but dimmer

### Third Oscillator (using Gate 4)

Gate 4 is unused in the basic design. You can add a third oscillator for even more complexity:
- Use a much slower rate (0.2–0.5 Hz) for a "breathing" layer
- Or a much faster rate (5–10 Hz) for a subtle "glitter" overlay

### PWM Dimming via Oscillator Mixing

Instead of driving LED banks directly, use the two oscillator outputs as inputs to an AND or OR gate (using the spare Gate 4) to create a combined pattern that drives a single LED bank through a transistor. This creates pulse patterns impossible with a single oscillator.

### Solar Panel Voltage Indicator

Add a single LED + high-value resistor (100 kΩ) from the solar panel output (before the diode) to GND. It will glow faintly during daylight to confirm the panels are producing power.

---

## Power Budget Deep Dive

### Standby (Daytime — LDR in light)

| Component | Current |
|---|---|
| CD4093 quiescent | ~5 µA |
| LDR divider | ~5 µA |
| **Total standby** | **~10 µA** |

At 10 µA, the battery would last **200,000 hours** (~23 years) on standby alone. Daytime power consumption is negligible.

### Active (Nighttime — LEDs on)

| Component | Current |
|---|---|
| CD4093 + oscillators | ~50 µA |
| Steady bank (5 LEDs × 0.4 mA) | ~2 mA |
| Twinkle bank 1 (5 LEDs × 0.27 mA × 50%) | ~0.68 mA |
| Twinkle bank 2 (5 LEDs × 0.27 mA × 50%) | ~0.68 mA |
| Base drive (3 × ~10 µA) | ~30 µA |
| **Total active** | **~3.4 mA** |

### Battery Life Without Solar

At 2000 mAh and 3.4 mA active draw:
- Continuous: ~588 hours (~24.5 days)
- 10 hrs/night: ~59 nights

### Solar Recharge Rate

Two 50 mA panels in parallel under indoor light (window sill, ~4 hrs effective sun):
- Daily charge: ~100 mA × 4 hrs = 400 mAh
- Daily discharge: 3.4 mA × 10 hrs = 34 mAh
- **Net daily surplus: +366 mAh** — the battery stays full indefinitely.

---

## References

- CD4093 datasheet: [Texas Instruments CD4093B](https://www.ti.com/product/CD4093B)
- 2N3904 datasheet: [ON Semiconductor 2N3904](https://www.onsemi.com/pdf/datasheet/2n3904-d.pdf)
- 1N5819 datasheet: [Vishay 1N5819](https://www.vishay.com/docs/88526/1n5819.pdf)
- NiMH charging guide: [Battery University — NiMH](https://batteryuniversity.com/article/bu-407-charging-nickel-metal-hydride)

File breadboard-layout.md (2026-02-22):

# Breadboard Layout — Diamond Mine Shimmer

## Board Overview

Standard 830-point solderless breadboard. Power rails top and bottom, IC centered,
components grouped by function zone.

Breadboard zone overview

```mermaid
graph TD
    subgraph "Breadboard Zones (left to right)"
        direction LR
        ZA["Zone A<br/>POWER INPUT<br/>Solar, R_charge,<br/>Diode, Battery<br/>(rows 1–5)"]
        ZB["Zone B<br/>DUSK DETECTOR<br/>LDR, R_sense,<br/>Trimpot<br/>(rows 6–14)"]
        ZC["Zone C<br/>IC + OSCILLATORS<br/>CD4093, RC networks,<br/>Fade cap<br/>(rows 15–35)"]
        ZD["Zone D<br/>TRANSISTORS<br/>Q1 (NPN), Q2/Q3 (PNP)<br/>(rows 38–52)"]
        ZE["Zone E<br/>LED BANKS<br/>Resistors + LEDs<br/>(rows 55–63)"]
        ZA --> ZB --> ZC --> ZD --> ZE
    end
```

---

## Power Rails

```
(+) rail ═══════════════════════════════════════════════ VDD (Battery+)
                    board top edge

 ... breadboard rows ...

(−) rail ═══════════════════════════════════════════════ GND (Battery−)
                    board bottom edge
```

Place a **0.1uF ceramic cap** spanning (+) and (−) rails near the IC location (around row 15).

---

## Zone A: Power Input (rows 1–5)

Power section — solar panels, R_charge, diode, battery connections

```
Row 1:  Solar+ wire → 10 ohm R_charge (1/2W) → Row 2
Row 2:  R_charge output → 1N5819 anode (band faces right toward row 3)
Row 3:  1N5819 cathode → jumper wire to (+) rail
Row 1:  Solar− wire → jumper to (−) rail
        Battery+ → (+) rail
        Battery− → (−) rail
```

> **R_charge (10 ohm, 1/2W):** Limits solar charge current to safe NiMH trickle
> range. Must be rated 1/2W minimum (0.48W worst-case dissipation).

---

## Zone B: Dusk Detector (rows 6–14)

```
Row 6:   (+) rail → LDR leg 1
Row 8:   LDR leg 2 (SENSE node)
Row 8:   jumper from here → Row 15 (Pin 1/2 node)
Row 8:   470k resistor: Row 8 → Row 11
Row 11:  100k trimpot wiper → Row 11
         trimpot end 1 → Row 11 (connects to 470k)
         trimpot end 2 → (−) rail
Row 11:  47k resistor → (−) rail
```

---

## Zone C: IC + Oscillators (rows 15–35)

CD4093 pinout and connections

Dusk detector, fade ramp, and oscillator RC networks

### Bypass Capacitor

```
Row 14:  0.1uF ceramic cap: (+) rail → (−) rail   (within 1 row of Pin 14)
```

### CD4093 Placement

IC straddles center channel at rows 15–21:

```
         Column E (lower)     Column F (upper)
Row 15:    Pin 1  ──────────  Pin 14    → wire to (+) rail
Row 16:    Pin 2  ──────────  Pin 13    → wire to (+) rail
Row 17:    Pin 3  ──────────  Pin 12    → wire to (+) rail
Row 18:    Pin 4  ──────────  Pin 11    (no connection)
Row 19:    Pin 5  ──────────  Pin 10
Row 20:    Pin 6  ──────────  Pin 9
Row 21:    Pin 7  ──────────  Pin 8
             │
             └→ wire to (−) rail
```

### IC-Side Jumpers

| From | To | Purpose |
|---|----|---|
| Row 15 col A (Pin 1) | Row 16 col A (Pin 2) | Tie Gate 1 inputs together |
| Row 16 col J (Pin 13) | (+) rail | Tie Gate 4 input A to VDD |
| Row 17 col J (Pin 12) | (+) rail | Tie Gate 4 input B to VDD |
| Row 15 col J (Pin 14) | (+) rail | IC power |
| Row 21 col E (Pin 7) | (−) rail | IC ground |

### DARK Signal Distribution (Pin 3, Row 17)

| From | To | Purpose |
|---|----|---|
| Row 17 col A | Row 19 col A (Pin 5) | Gate oscillator 1 |
| Row 17 col A | Row 21 col J (Pin 8) | Gate oscillator 2 |
| Row 17 col C | Row 23 (470k to FADE) | Start of fade ramp |

### Fade-In Ramp

```
Row 23:  470k resistor: Row 17 col C → Row 23
Row 25:  100uF electrolytic (+) at Row 25, (−) to (−) rail
         Row 23 → Row 25 jumper (FADE node)
```

### Oscillator 1 (Gate 2)

```
Row 18 col A (Pin 4 output):
    1M resistor: Row 18 col A → Row 28
Row 28:
    100k trimpot: Row 28 → Row 30
Row 30 (RC1 node):
    jumper → Row 20 col A (Pin 6)
    0.47uF film cap: Row 30 → (−) rail
```

### Oscillator 2 (Gate 3)

```
Row 19 col J (Pin 10 output):
    1M resistor: Row 19 col J → Row 33
Row 33:
    100k trimpot: Row 33 → Row 35
Row 35 (RC2 node):
    jumper → Row 20 col J (Pin 9)
    0.47uF film cap: Row 35 → (−) rail
```

---

## Zone D: Transistors (rows 38–52)

Transistor orientation — E-B-C pin order, NPN vs PNP wiring

All transistors: flat side facing you, pins left-to-right: E, B, C.

### Q1 — Steady Bank Driver (NPN 2N3904)

```
Row 40:  col A = Emitter → (−) rail
         col B = Base    ← 10k ← FADE node (Row 25)
         col C = Collector → jumper to Steady LED bank
```

### Q2 — Twinkle Bank 1 Driver (PNP 2N3906)

```
Row 45:  col A = Emitter → (+) rail       ← NOTE: VDD, not GND
         col B = Base    ← 100k ← Pin 4 / OSC1 (Row 18 col A)
         col C = Collector → jumper to Twinkle LED bank 1
```

### Q3 — Twinkle Bank 2 Driver (PNP 2N3906)

```
Row 50:  col A = Emitter → (+) rail       ← NOTE: VDD, not GND
         col B = Base    ← 100k ← Pin 10 / OSC2 (Row 19 col J)
         col C = Collector → jumper to Twinkle LED bank 2
```

> **PNP wiring:** Q2 and Q3 emitters connect to (+) VDD rail, NOT (−) GND.
> This is the opposite of Q1 (NPN). The PNP high-side topology ensures the
> twinkle LEDs are completely OFF when DARK = LOW (daytime).

---

## Zone E: LED Banks (rows 55–63)

LED wiring — Steady bank vs Twinkle bank topology and polarity

### Steady Bank (NPN Q1: VDD → resistor → LED → Q1 collector)

Each LED: anode via resistor to (+) rail, cathode to Q1 collector.

```
Row 55:  1.5k from (+) rail → LED anode, LED cathode → wire to Row 40 col D
Row 56:  1.5k from (+) rail → LED anode, LED cathode → wire to Row 40 col D
Row 57:  1.5k from (+) rail → LED anode, LED cathode → wire to Row 40 col D
```

### Twinkle Bank 1 (PNP Q2: Q2 collector → LED → resistor → GND)

Each LED: anode from Q2 collector, cathode via resistor to (−) rail.

```
Row 58:  wire from Row 45 col D → LED anode, LED cathode → 2.2k → (−) rail
Row 59:  wire from Row 45 col D → LED anode, LED cathode → 2.2k → (−) rail
Row 60:  wire from Row 45 col D → LED anode, LED cathode → 2.2k → (−) rail
```

### Twinkle Bank 2 (PNP Q3: Q3 collector → LED → resistor → GND)

Each LED: anode from Q3 collector, cathode via resistor to (−) rail.

```
Row 61:  wire from Row 50 col D → LED anode, LED cathode → 2.2k → (−) rail
Row 62:  wire from Row 50 col D → LED anode, LED cathode → 2.2k → (−) rail
Row 63:  wire from Row 50 col D → LED anode, LED cathode → 2.2k → (−) rail
```

> **Topology difference:** Steady bank LEDs connect VDD-side resistor → LED → Q1
> collector. Twinkle bank LEDs connect Q2/Q3 collector → LED → GND-side resistor.
> This reversal is required for the PNP high-side switch topology.

---

## Wire Color Guide

```mermaid
graph LR
    RED["RED<br/>VDD power"] ~~~ BLACK["BLACK<br/>GND ground"]
    YELLOW["YELLOW<br/>DARK signal<br/>(Pin 3 → Pin 5, Pin 8, 470k)"] ~~~ ORANGE["ORANGE<br/>FADE node<br/>(100uF → 10k → Q1)"]
    GREEN["GREEN<br/>OSC1 output<br/>(Pin 4 → 100k → Q2)"] ~~~ BLUE["BLUE<br/>OSC2 output<br/>(Pin 10 → 100k → Q3)"]
    WHITE["WHITE<br/>LDR SENSE node<br/>(LDR → Pin 1/2)"]

    style RED fill:#cc0000,color:#fff
    style BLACK fill:#222222,color:#fff
    style YELLOW fill:#ffcc00,color:#000
    style ORANGE fill:#ff8800,color:#000
    style GREEN fill:#22aa22,color:#fff
    style BLUE fill:#2266cc,color:#fff
    style WHITE fill:#eeeeee,color:#000
```

| Color | Signal | From → To |
|---|---|---|
| Red | VDD | (+) rail → Pin 14, Pin 12, Pin 13, LDR, Steady LED resistors, Q2/Q3 emitters |
| Black | GND | (−) rail → Pin 7, Q1 emitter, caps, trimpot ends, Twinkle LED resistors |
| Yellow | DARK | Pin 3 → Pin 5, Pin 8, 470k fade resistor |
| Orange | FADE | 470k/100uF junction → 10k → Q1 base |
| Green | OSC1 | Pin 4 → 1M (feedback) and 100k → Q2 base |
| Blue | OSC2 | Pin 10 → 1M (feedback) and 100k → Q3 base |
| White | SENSE | LDR → Pin 1, Pin 2, 470k divider top |

---

## Layout Tips

1. **Keep bypass cap close to IC** — The 0.1uF ceramic should be within 1–2 rows of pins 7 and 14.
2. **Electrolytic polarity** — The 100uF fade cap has a stripe marking the negative leg. Negative to (−) rail.
3. **Trimpot orientation** — Mount trimpots with adjustment screw facing outward for easy tuning.
4. **LED polarity** — Longer leg = anode. Flat edge on lens = cathode.
5. **NPN (Q1) vs PNP (Q2, Q3)** — Q1 emitter to GND. Q2/Q3 emitters to VDD. All three: flat side facing you, E-B-C left to right.
6. **Film vs electrolytic** — Use film caps (0.47uF) for oscillators (non-polarized). Use electrolytic (100uF) only for the fade ramp (polarized, observe +/−).
7. **R_charge heat** — The 10 ohm resistor may get warm in full sun. Use 1/2W rating and leave airspace around it.

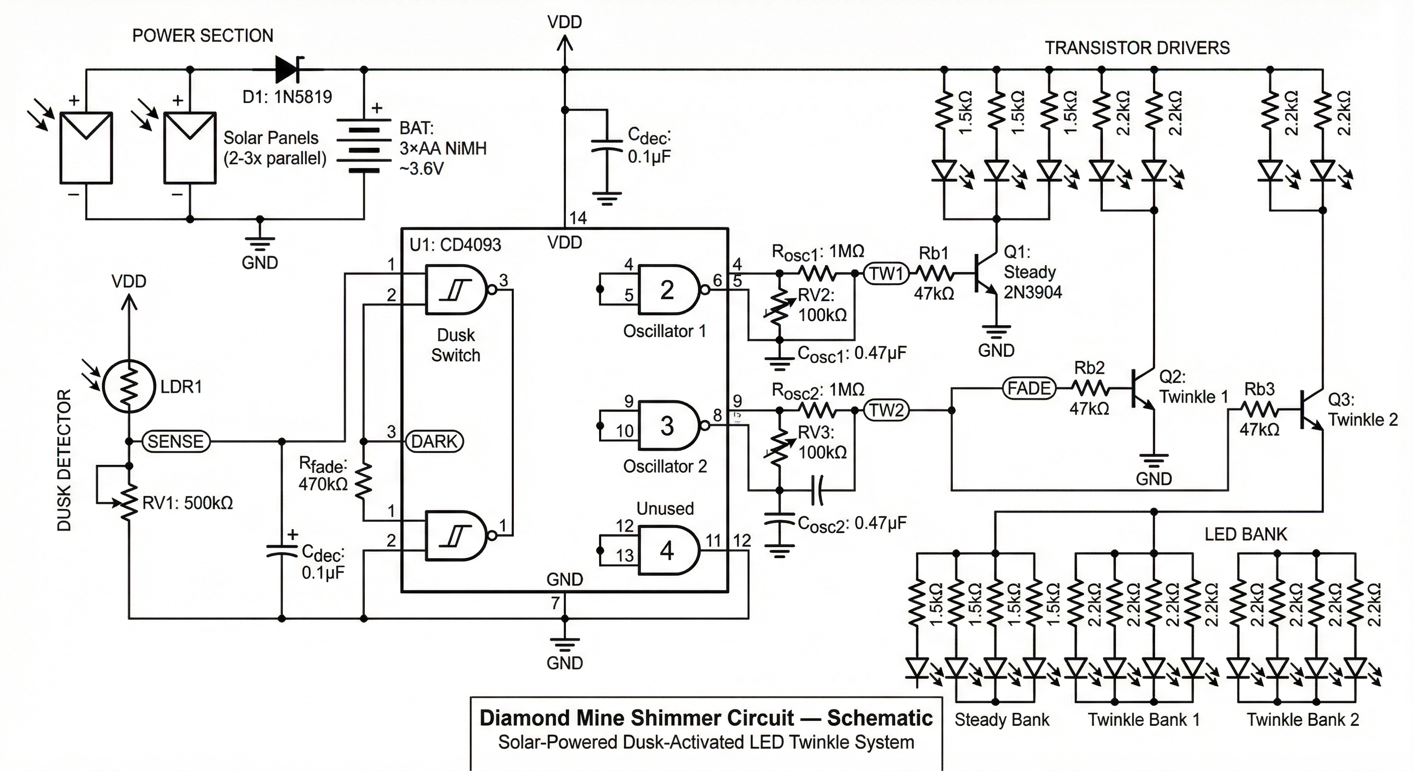
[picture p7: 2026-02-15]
assets/schematic.png

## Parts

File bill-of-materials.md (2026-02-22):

# Bill of Materials — Diamond Mine Shimmer

## Active Components

| Qty | Part | Package | Notes |
|-----|---|---|---|
| 1 | CD4093BE | DIP-14 | Quad Schmitt-trigger NAND gate. TI or ON Semi. |
| 1 | 2N3904 | TO-92 | NPN general-purpose transistor (Q1 — steady bank). |
| 2 | 2N3906 | TO-92 | PNP general-purpose transistor (Q2, Q3 — twinkle banks). |
| 1 | 1N5819 | DO-41 | Schottky diode, solar charge blocking. Vf ~0.3V. |
| 1 | LDR (GL5528) | 5mm | Light-dependent resistor, ~5k bright / ~500k dark. |

## Capacitors

| Qty | Value | Type | Purpose |
|-----|---|---|---|
| 1 | 0.1uF | Ceramic (104) | IC bypass decoupling across VDD/GND |
| 2 | 0.47uF | Film (474) | Oscillator timing caps (C1, C2) |
| 1 | 100uF / 10V+ | Electrolytic | Fade-in ramp. **Observe polarity.** |

## Fixed Resistors

| Qty | Value | Rating | Purpose |
|-----|---|---|---|
| 1 | 10 ohm | **1/2W** | Solar charge current limiter (R_charge) |
| 1 | 470k | 1/4W 5% | Dusk threshold (fixed portion of divider) |
| 1 | 47k | 1/4W 5% | Dusk threshold (parallel pulldown) |
| 1 | 470k | 1/4W 5% | Fade-in ramp charging resistor |
| 2 | 1M | 1/4W 5% | Oscillator timing (fixed portion, one per osc) |
| 2 | 100k | 1/4W 5% | Oscillator output to PNP base drive (Q2, Q3) |
| 1 | 10k | 1/4W 5% | Fade node to Q1 base drive |
| 3 | 1.5k | 1/4W 5% | Steady bank LED current limit (~0.9 mA each) |
| 6 | 2.2k | 1/4W 5% | Twinkle bank LED current limit (~0.6 mA each) |

**Total fixed resistors: 18**

## Trimpots (Adjustable)

| Qty | Value | Type | Purpose |
|-----|---|---|---|
| 1 | 100k | 3-pin cermet or carbon | Dusk sensitivity — sets LDR trigger point |
| 2 | 100k | 3-pin cermet or carbon | Twinkle speed 1 and 2 — adjusts oscillator frequency |

## LEDs

| Qty | Color | Purpose | Current |
|-----|---|---|---|
| 3 | Red, Amber, or Yellow | Steady bank (base glow) | ~0.9 mA each |
| 3 | Red, Amber, or Yellow | Twinkle bank 1 | ~0.6 mA each |
| 3 | Red, Amber, or Yellow | Twinkle bank 2 | ~0.6 mA each |

**Total LEDs: 9** (scale up or down as desired)

> **LED color note:** Red/amber/yellow LEDs (Vf ~1.8–2.1V) work best with a 3.6V
> supply. White or blue LEDs (Vf ~3.0–3.2V) will be very dim at these resistor
> values. If white is desired, reduce LED resistors to 470 ohm and expect higher
> current draw.

## Power

| Qty | Part | Notes |
|-----|---|---|
| 3 | AA NiMH rechargeable | 1.2V nominal, 2000 mAh. Eneloop recommended. |
| 1 | 3xAA battery holder | With wire leads. |
| 2–3 | Solar panels (5.5V) | 5–6V, 80–100 mA each. Wired in parallel. Indoor-rated. |

## Mechanical

| Qty | Part | Notes |
|-----|---|---|
| 1 | 830-point breadboard | Standard solderless. One board is sufficient. |
| 1 | Jumper wire kit | 22 AWG solid core, assorted colors. |
| 1 | DIP-14 socket (optional) | Protects IC during soldering if transferring to perfboard. |

---

## LED Current Calculations

### Steady Bank (1.5k resistors, NPN low-side Q1)

```
I = (VDD - Vf_LED - Vce_sat) / R
I = (3.6 - 2.0 - 0.2) / 1500
I = 1.4 / 1500
I = 0.93 mA per LED
```

### Twinkle Banks (2.2k resistors, PNP high-side Q2/Q3)

```
I = (VDD - Vce_sat - Vf_LED) / R
I = (3.6 - 0.2 - 2.0) / 2200
I = 1.4 / 2200
I = 0.64 mA per LED
```

### Transistor Base Drive

```
Q1 (NPN, steady):
  Ib = (V_FADE - Vbe) / 10k
  Ib_max = (3.6 - 0.7) / 10k = 0.29 mA
  Ic_max = hFE x Ib = 100 x 0.29 mA = 29 mA  (plenty for 3 LEDs at 0.93 mA)

Q2/Q3 (PNP, twinkle):
  Ib = (VDD - Vbe - V_base) / 100k
  When output LOW:  Ib = (3.6 - 0.7 - 0) / 100k = 29 uA
  When output HIGH: Ib = (3.6 - 0.7 - 3.6) / 100k < 0  → OFF
  Ic_max = hFE x Ib = 100 x 29 uA = 2.9 mA  (sufficient for 3 LEDs at 0.64 mA = 1.92 mA)
```

### Solar Charge Current

```
R_charge = 10 ohm (1/2W)

At minimum battery (3.0V, deeply discharged):
  I = (5.5 - 0.3 - 3.0) / 10 = 220 mA  (C/9, acceptable for NiMH)

At nominal battery (3.6V):
  I = (5.5 - 0.3 - 3.6) / 10 = 160 mA  (C/12.5, safe)

At maximum battery (4.35V, fully charged):
  I = (5.5 - 0.3 - 4.35) / 10 = 85 mA   (C/24, indefinite trickle safe)

Power in R_charge: P_max = 0.22^2 x 10 = 0.48W → use 1/2W resistor
```

---

## Cost Estimate (approximate, 2026 USD)

| Category | Estimated Cost |
|---|---|
| CD4093 + socket | $1.50 |
| 1x 2N3904 + 2x 2N3906 | $1.50 |
| 1N5819 | $0.50 |
| LDR | $0.50 |
| Resistor assortment (if needed) | $5.00 |
| 3x trimpots | $2.00 |
| Capacitors | $1.50 |
| 9x LEDs | $2.00 |
| 3x AA NiMH batteries (Eneloop) | $10.00 |
| Battery holder | $1.50 |
| 2x solar panels (5.5V) | $8.00 |
| Breadboard + jumper wires | $6.00 |
| **Total** | **~$40** |

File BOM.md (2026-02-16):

# Bill of Materials (BOM)

> Diamond Mine Shimmer Circuit — complete parts list with values, quantities, and sourcing notes.

---

## Power + Charging Section

| Qty | Part | Value / Rating | Reference | Notes |
|-----|---|---|---|---|
| 3 | AA NiMH rechargeable cells | 1.2 V / 2000 mAh typ. | BAT1–3 | Eneloop or similar low-self-discharge preferred |
| 1 | 3×AA battery holder | — | — | With leads or snap connector |
| 2–3 | Small indoor solar panels | 2 V / 20–40 mA each | SOL1–3 | Wire in **parallel** (same voltage, additive current); keep total \(I_{SC}\) at or below ~80 mA for 2000 mAh cells |
| 1 | 1N5819 Schottky diode | 40 V / 1 A | D1 | Prevents battery discharging back through panels at night |

### Charging Notes

- Typical indoor current is usually much lower than panel nameplate current; expect roughly 5–40 mA depending on light and panel orientation.
- The Schottky diode drops only ~0.2 V vs ~0.6 V for a standard 1N4001 — important at a 3.6 V rail.
- For long-term safe trickle charging of 2000 mAh NiMH cells, keep sustained charge current at or below ~C/25 to C/20 (about 80–100 mA max).
- If you expect strong sunlight exposure, reduce panel count or add charge-current limiting.

---

## Logic + Control Section

| Qty | Part | Value / Rating | Reference | Notes |
|-----|---|---|---|---|
| 1 | CD4093 | Quad 2-input Schmitt-trigger NAND | U1 | CMOS, runs 3–18 V, ultra-low quiescent current |
| 1 | LDR (photoresistor) | ~10 kΩ (light) / ~1 MΩ (dark) | LDR1 | GL5528 or similar; any CdS photoresistor works |
| 1 | Potentiometer | 500 kΩ linear | RV1 | Dusk sensitivity adjustment |

### IC Pinout Reference (CD4093)

```
        ┌───U───┐
  1A  1 │       │ 14  VDD
  1B  2 │       │ 13  4A
  1Y  3 │       │ 12  4B
  2A  4 │CD4093 │ 11  4Y
  2B  5 │       │ 10  3A
  2Y  6 │       │  9  3B
 GND  7 │       │  8  3Y
        └───────┘
```

Gate assignments in this circuit:
- **Gate 1** (pins 1, 2 → 3): Dusk detector / enable switch
- **Gate 2** (pins 4, 5 → 6): Twinkle oscillator 1
- **Gate 3** (pins 9, 10 → 8): Twinkle oscillator 2
- **Gate 4** (pins 12, 13 → 11): Unused — tie inputs to VDD or GND

---

## Fade-In Ramp Section

| Qty | Part | Value | Reference | Notes |
|-----|---|---|---|---|
| 1 | Resistor | 470 kΩ ¼W | R_fade | Fade charge resistor; controls ramp speed |
| 1 | Electrolytic capacitor | 100 µF / 10 V | C_fade | Fade ramp storage; low-ESR preferred |

### Fade Timing

τ = R × C = 470 kΩ × 100 µF = **47 seconds**

The LEDs reach ~63% brightness in 47 s and ~95% in ~2.5 minutes — a gentle, organic bloom.

---

## Oscillator Section (×2 Twinkle Channels)

| Qty | Part | Value | Reference | Notes |
|-----|---|---|---|---|
| 2 | Resistor | 1 MΩ ¼W | R_osc1, R_osc2 | Oscillator timing resistors |
| 2 | Trimmer potentiometer | 100 kΩ | RV2, RV3 | Twinkle speed fine-tune |
| 2 | Film capacitor | 0.47 µF (470 nF) | C_osc1, C_osc2 | Timing caps; film preferred over ceramic for stability |

### Oscillator Frequency Estimates

Using f ≈ 1 / (1.2 × R × C) for a Schmitt-trigger oscillator:

| Trim pot setting | Total R | Frequency | Period |
|---|---|---|---|
| 0 Ω (bypassed) | 1.0 MΩ | ~1.8 Hz | ~0.57 s |
| 50 kΩ | 1.05 MΩ | ~1.7 Hz | ~0.59 s |
| 100 kΩ (max) | 1.1 MΩ | ~1.6 Hz | ~0.63 s |

Adjust each channel's trim pot so the two rates are **slightly different** (e.g., 1.6 Hz vs 1.8 Hz). The resulting beat frequency creates a slow, drifting shimmer pattern.

---

## LED Driver Stage

| Qty | Part | Value | Reference | Notes |
|-----|---|---|---|---|
| 2–3 | NPN transistor | 2N3904 | Q1, Q2, Q3 | Or BC547, 2N2222 — any small-signal NPN |
| 3 | Base resistor | 10 kΩ–220 kΩ | R_b1–R_b3 | Limits base current; 47 kΩ is a good starting point |
| 2 | Signal diode | 1N4148 | D_t1, D_t2 | Twinkle base clamp to guarantee OFF during daylight |

### Transistor Selection Notes

- 2N3904: V_CE(sat) ≈ 0.2 V, h_FE ≥ 100 — plenty for LED-driving duty.
- At 3.6 V rail and ~2 mA per LED, collector current stays well under the 200 mA max.
- For the steady-glow channel (Q1), the fade ramp voltage rises slowly, so Q1 acts as a variable gain amplifier during fade-in.

---

## LED Banks

| Qty | Part | Value | Reference | Notes |
|-----|---|---|---|---|
| 3–6 | Warm white LED | 3 mm or 5 mm diffused | D_s1–D_s6 | Steady bank — "base glow" |
| 4–7 | Warm white LED | 3 mm or 5 mm diffused | D_t1–D_t7 | Twinkle bank 1 |
| 4–7 | Warm white LED | 3 mm or 5 mm diffused | D_t8–D_t14 | Twinkle bank 2 |
| 3–6 | Resistor | 1.5 kΩ ¼W | R_Ls | Steady LED current limiters |
| 4–7 | Resistor | 2.2 kΩ ¼W | R_Lt1 | Twinkle 1 LED current limiters |
| 4–7 | Resistor | 2.2 kΩ ¼W | R_Lt2 | Twinkle 2 LED current limiters |

### LED Current Estimates

At V_DD = 3.6 V, V_LED ≈ 2.8 V (warm white), V_CE(sat) ≈ 0.2 V:

| Bank | Resistor | I_LED | Brightness |
|---|---|---|---|
| Steady | 1.5 kΩ | ~0.4 mA | Dim warm glow |
| Twinkle | 2.2 kΩ | ~0.27 mA | Subtle sparkle |

These are intentionally low currents — the "diamond mine" aesthetic calls for delicate pinpoints of light, not blazing floodlights. For brighter results, reduce resistor values (minimum ~220 Ω for standard LEDs).

---

## Decoupling

| Qty | Part | Value | Reference | Notes |
|-----|---|---|---|---|
| 1 | Ceramic capacitor | 0.1 µF (100 nF) | C_dec | Place as close to CD4093 VDD/GND pins as possible |

---

## Summary Totals

| Category | Count |
|---|---|
| Resistors | ~15–20 |
| Capacitors | 5 |
| Transistors | 3 |
| LEDs | 10–20 |
| ICs | 1 |
| Diodes | 3 |
| Potentiometers | 3 |
| Solar panels | 2–3 |
| Battery cells | 3 |

**Estimated total cost:** $8–$15 USD (excluding battery holder and solar panels from common component kits)

---

## Recommended Suppliers

- **Mouser / Digi-Key** — full catalog, exact values
- **Amazon / AliExpress** — component assortment kits (resistor kits, LED bags, solar panels)
- **Tayda Electronics** — budget-friendly discrete components
- **Adafruit / SparkFun** — solar panels, battery holders, and prototyping supplies

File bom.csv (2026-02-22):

Reference | Quantity | Value | Package | Description | Category | Notes
U1 | 1 | CD4093BE | DIP-14 | Quad Schmitt-trigger NAND gate | IC | TI or ON Semi
Q1 | 1 | 2N3904 | TO-92 | NPN general-purpose transistor | Transistor | Steady bank driver (low-side)
Q2 | 1 | 2N3906 | TO-92 | PNP general-purpose transistor | Transistor | Twinkle bank 1 driver (high-side)
Q3 | 1 | 2N3906 | TO-92 | PNP general-purpose transistor | Transistor | Twinkle bank 2 driver (high-side)
D1 | 1 | 1N5819 | DO-41 | Schottky diode 40V 1A | Diode | Solar charge blocking Vf~0.3V
LDR1 | 1 | GL5528 | 5mm | Light-dependent resistor | Sensor | ~5k bright / ~500k dark
C_bypass | 1 | 0.1uF | Ceramic 104 | Bypass decoupling capacitor | Capacitor | Close to IC VDD/GND
C1 | 1 | 0.47uF | Film 474 | Oscillator 1 timing cap | Capacitor | Film preferred for stability
C2 | 1 | 0.47uF | Film 474 | Oscillator 2 timing cap | Capacitor | Film preferred for stability
C_fade | 1 | 100uF 10V+ | Electrolytic | Fade-in ramp capacitor | Capacitor | Observe polarity
R_charge | 1 | 10 ohm | Axial 1/2W | Solar charge current limiter | Resistor | 1/2W minimum rating
R_div1 | 1 | 470k | Axial 1/4W 5% | Dusk threshold fixed portion | Resistor
R_div2 | 1 | 47k | Axial 1/4W 5% | Dusk threshold parallel pulldown | Resistor
R_fade | 1 | 470k | Axial 1/4W 5% | Fade-in ramp charging resistor | Resistor | tau = 470k x 100uF = 47s
R_osc1 | 1 | 1M | Axial 1/4W 5% | Oscillator 1 timing fixed | Resistor
R_osc2 | 1 | 1M | Axial 1/4W 5% | Oscillator 2 timing fixed | Resistor
R_b2 | 1 | 100k | Axial 1/4W 5% | OSC1 to Q2 PNP base drive | Resistor
R_b3 | 1 | 100k | Axial 1/4W 5% | OSC2 to Q3 PNP base drive | Resistor
R_b1 | 1 | 10k | Axial 1/4W 5% | FADE to Q1 NPN base drive | Resistor
R_Ls1 | 1 | 1.5k | Axial 1/4W 5% | Steady bank LED 1 current limit | Resistor | ~0.93 mA
R_Ls2 | 1 | 1.5k | Axial 1/4W 5% | Steady bank LED 2 current limit | Resistor | ~0.93 mA
R_Ls3 | 1 | 1.5k | Axial 1/4W 5% | Steady bank LED 3 current limit | Resistor | ~0.93 mA
R_Lt1 | 1 | 2.2k | Axial 1/4W 5% | Twinkle 1 LED 1 current limit | Resistor | ~0.64 mA
R_Lt2 | 1 | 2.2k | Axial 1/4W 5% | Twinkle 1 LED 2 current limit | Resistor | ~0.64 mA
R_Lt3 | 1 | 2.2k | Axial 1/4W 5% | Twinkle 1 LED 3 current limit | Resistor | ~0.64 mA
R_Lt4 | 1 | 2.2k | Axial 1/4W 5% | Twinkle 2 LED 1 current limit | Resistor | ~0.64 mA
R_Lt5 | 1 | 2.2k | Axial 1/4W 5% | Twinkle 2 LED 2 current limit | Resistor | ~0.64 mA
R_Lt6 | 1 | 2.2k | Axial 1/4W 5% | Twinkle 2 LED 3 current limit | Resistor | ~0.64 mA
RV1 | 1 | 100k | 3-pin trimmer | Dusk sensitivity trimpot | Potentiometer | Cermet or carbon
RV2 | 1 | 100k | 3-pin trimmer | Twinkle speed 1 trimpot | Potentiometer | Cermet or carbon
RV3 | 1 | 100k | 3-pin trimmer | Twinkle speed 2 trimpot | Potentiometer | Cermet or carbon
D_Ls1 | 1 | LED Red/Amber | 3mm or 5mm | Steady bank LED 1 | LED | Vf ~1.8-2.1V
D_Ls2 | 1 | LED Red/Amber | 3mm or 5mm | Steady bank LED 2 | LED | Vf ~1.8-2.1V
D_Ls3 | 1 | LED Red/Amber | 3mm or 5mm | Steady bank LED 3 | LED | Vf ~1.8-2.1V
D_Lt1 | 1 | LED Red/Amber | 3mm or 5mm | Twinkle 1 LED 1 | LED | Vf ~1.8-2.1V
D_Lt2 | 1 | LED Red/Amber | 3mm or 5mm | Twinkle 1 LED 2 | LED | Vf ~1.8-2.1V
D_Lt3 | 1 | LED Red/Amber | 3mm or 5mm | Twinkle 1 LED 3 | LED | Vf ~1.8-2.1V
D_Lt4 | 1 | LED Red/Amber | 3mm or 5mm | Twinkle 2 LED 1 | LED | Vf ~1.8-2.1V
D_Lt5 | 1 | LED Red/Amber | 3mm or 5mm | Twinkle 2 LED 2 | LED | Vf ~1.8-2.1V
D_Lt6 | 1 | LED Red/Amber | 3mm or 5mm | Twinkle 2 LED 3 | LED | Vf ~1.8-2.1V
BAT1-3 | 3 | AA NiMH | AA cell | Rechargeable battery | Power | 1.2V 2000mAh Eneloop recommended
BH1 | 1 | 3xAA holder |  | Battery holder with leads | Mechanical
SOL1 | 1 | Solar panel 5.5V |  | 5-6V 80-100mA indoor panel | Power | Wire in parallel
SOL2 | 1 | Solar panel 5.5V |  | 5-6V 80-100mA indoor panel | Power | Wire in parallel
BB1 | 1 | 830-point breadboard |  | Solderless prototyping board | Mechanical
JW1 | 1 | Jumper wire kit |  | 22 AWG solid core assorted | Mechanical
SK1 | 1 | DIP-14 socket |  | IC socket (optional) | Mechanical | Protects IC during soldering

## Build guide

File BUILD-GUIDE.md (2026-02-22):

# Build Guide — Diamond Mine Shimmer (Breadboard Prototype)

Step-by-step assembly and testing for the corrected circuit on a solderless
breadboard. Follow in order — each phase includes a verification step so you
catch wiring errors before they compound.

## Breadboard Assembly Diagrams

Quick-reference PNG diagrams — print or keep on a second screen while building.

Breadboard zone overview

| Diagram | File | Use When |
|---|---|---|
| **Breadboard zones** | `diamond-mine-breadboard-overview.png` | Planning layout — where each section goes |
| **CD4093 pinout** | `diamond-mine-cd4093-pinout.png` | Placing IC and wiring pins 1–14 |
| **Transistor orientation** | `diamond-mine-transistor-orientation.png` | Q1/Q2/Q3 — flat side, E–B–C, PNP vs NPN |
| **LED wiring** | `diamond-mine-led-wiring.png` | Steady vs Twinkle banks — polarity and topology |
| **Power section** | `diamond-mine-power-section.png` | Solar, R_charge, diode, battery polarity |
| **Dusk & oscillators** | `diamond-mine-dusk-and-oscillators.png` | LDR divider, RC networks, capacitor polarity |

---

**Required references during assembly:**
- [breadboard-layout.md](breadboard-layout.md) — physical row/column placement
- [schematic.md](schematic.md) — electrical connections
- [bill-of-materials.md](bill-of-materials.md) — parts list

---

## Tools Required

- Multimeter (DC voltage, continuity)
- Needle-nose pliers and wire cutters
- Small flat-blade screwdriver (for trimpots)
- 830-point solderless breadboard
- 22 AWG solid-core jumper wire kit (assorted colors)
- Dark cloth or opaque cup (to cover LDR during testing)

---

## Phase 1 — Power Rails

Power section wiring — solar, R_charge, diode, battery

### Step 1: Battery and Rails

1. Connect 3x AA NiMH cells into the battery holder (series = ~3.6V).
2. Wire Battery+ to the (+) rail, Battery- to the (-) rail.
3. Measure across the rails with a multimeter: expect 3.6–4.0V.

### Step 2: Solar Charge Path

1. Insert the 10-ohm (1/2W) resistor from Row 1 to Row 2.
2. Insert the 1N5819 Schottky diode: anode at Row 2, cathode (banded end) at Row 3.
3. Jumper from Row 3 to the (+) rail.
4. Connect Solar+ wire to Row 1, Solar- wire to the (-) rail.

### Step 3: Bypass Capacitor

1. Place a 0.1uF ceramic cap spanning the (+) and (-) rails at Row 14
   (within one row of where Pin 14 will land).

### Verify Phase 1

- Disconnect solar panels (or cover them).
- Measure (+) to (-) rail: should read battery voltage (~3.6V).
- With panels connected in light: measure voltage at Row 1 (solar side of R_charge).
  Should read ~5V. Measure at Row 3 (after diode): should read ~4.5–5V.

---

## Phase 2 — CD4093 IC

CD4093 pinout — notch orientation, pin numbering, and connections

### Step 4: IC Socket / Placement

1. Place the CD4093 (or DIP-14 socket) straddling the center channel at rows 15–21.
   Pin 1 at Row 15 col E, Pin 14 at Row 15 col F.
2. Wire Pin 14 (Row 15, col J side) to (+) rail — IC power.
3. Wire Pin 7 (Row 21, col E side) to (-) rail — IC ground.

### Step 5: Unused Gate 4

1. Wire Pin 13 (Row 16, col J) to (+) rail.
2. Wire Pin 12 (Row 17, col J) to (+) rail.
3. Leave Pin 11 unconnected.

### Step 6: Tie Gate 1 Inputs

1. Jumper from Row 15 col A (Pin 1) to Row 16 col A (Pin 2).

### Verify Phase 2

- Power on. Measure Pin 14 vs Pin 7: should read ~3.6V.
- Measure Pin 11 (Gate 4 output): should read near 0V (NAND with both inputs HIGH = LOW).
- Touch a jumper wire from Pin 1 to (-) rail briefly: Pin 3 should snap HIGH (~3.6V).
  Release: Pin 3 should return LOW.

---

## Phase 3 — Dusk Detector

Dusk detector, fade ramp, and oscillator RC networks

### Step 7: LDR and Divider

1. Insert LDR: one leg at Row 6 (wire to (+) rail), other leg at Row 8 (SENSE node).
2. Jumper from Row 8 to Row 15 col A (connects SENSE to Pin 1/2).
3. Insert 470k resistor from Row 8 to Row 11.
4. Wire the 100k dusk trimpot: wiper + end 1 at Row 11, end 2 to (-) rail.
5. Insert 47k resistor from Row 11 to (-) rail.

### Verify Phase 3

- In room light: measure Pin 3 (Row 17, col A). Should read near 0V (LOW).
- Cover LDR with dark cloth: Pin 3 should snap to ~3.6V (HIGH).
- Adjust the dusk trimpot until the transition happens at your desired light level.
- Uncover LDR: Pin 3 should return LOW cleanly (no flickering — Schmitt hysteresis).

---

## Phase 4 — Fade-In Ramp

### Step 8: RC Network

1. Insert 470k resistor from Row 17 col C (DARK/Pin 3) to Row 23.
2. Jumper from Row 23 to Row 25 (FADE node).
3. Insert 100uF electrolytic: positive leg at Row 25, negative leg to (-) rail.

### Verify Phase 4

- Cover LDR (DARK = HIGH).
- Probe Row 25 (FADE node): voltage should start at ~0V and rise slowly toward 3.6V.
- After ~10 seconds: expect ~0.7V. After ~47 seconds: expect ~2.3V.
- Uncover LDR: voltage should drop back toward 0V within a few seconds.

---

## Phase 5 — Oscillators

### Step 9: Oscillator 1 (Gate 2)

1. Jumper DARK signal: Row 17 col A to Row 19 col A (connects Pin 3 to Pin 5).
2. Insert 1M resistor from Row 18 col A (Pin 4, output) to Row 28.
3. Wire 100k trimpot: Row 28 to Row 30.
4. Jumper from Row 30 to Row 20 col A (connects RC node to Pin 6).
5. Insert 0.47uF film cap from Row 30 to (-) rail.

### Step 10: Oscillator 2 (Gate 3)

1. Jumper DARK signal: Row 17 col A to Row 21 col J (connects Pin 3 to Pin 8).
2. Insert 1M resistor from Row 19 col J (Pin 10, output) to Row 33.
3. Wire 100k trimpot: Row 33 to Row 35.
4. Jumper from Row 35 to Row 20 col J (connects RC node to Pin 9).
5. Insert 0.47uF film cap from Row 35 to (-) rail.

### Verify Phase 5

- Cover LDR (DARK = HIGH).
- Probe Pin 4 (Row 18): should see a square wave. An LED + 1k resistor temporarily
  clipped from Pin 4 to (-) rail will blink visibly at ~2–3 Hz.
- Probe Pin 10 (Row 19 col J): same, slightly different rate.
- Adjust trimpots so the two rates are close but not identical. Recommended: RV2 at
  ~30%, RV3 at ~70%.
- Uncover LDR: both outputs should go HIGH and stay there (no blinking).

---

## Phase 6 — Transistor Drivers

Transistor orientation — E-B-C pin order, NPN vs PNP wiring

### Step 11: Q1 — Steady Bank (NPN 2N3904)

1. Insert 2N3904 at Row 40 (flat side facing you: E-B-C left to right).
2. Wire col A (Emitter) to (-) rail.
3. Insert 10k resistor from FADE node (Row 25) to Row 40 col B (Base).
4. Col C (Collector) will connect to steady LEDs in Phase 7.

### Step 12: Q2 — Twinkle Bank 1 (PNP 2N3906)

1. Insert 2N3906 at Row 45 (flat side facing you: E-B-C left to right).
2. Wire col A (Emitter) to **(+) rail** — not GND! PNP emitter goes to VDD.
3. Insert 100k resistor from Pin 4/OSC1 (Row 18 col A) to Row 45 col B (Base).
4. Col C (Collector) will connect to twinkle LEDs in Phase 7.

### Step 13: Q3 — Twinkle Bank 2 (PNP 2N3906)

1. Insert 2N3906 at Row 50 (flat side facing you: E-B-C left to right).
2. Wire col A (Emitter) to **(+) rail**.
3. Insert 100k resistor from Pin 10/OSC2 (Row 19 col J) to Row 50 col B (Base).
4. Col C (Collector) will connect to twinkle LEDs in Phase 7.

### Verify Phase 6

- Cover LDR. Wait ~15 seconds for FADE to rise.
- Measure Q1 collector (Row 40 col C) to (-) rail: should show low voltage
  (transistor pulling toward GND), confirming Q1 is ON.
- Measure Q2 emitter (Row 45 col A) to Q2 collector (Row 45 col C): should toggle
  between ~0V (OFF) and ~3.4V (ON) at the oscillator rate.
- Same for Q3.
- Uncover LDR: all transistors should turn OFF. Q1 collector floats, Q2/Q3
  collectors float (no current path yet without LEDs).

---

## Phase 7 — LED Banks

LED wiring — Steady bank vs Twinkle bank topology and polarity

### Step 14: Steady Bank (3 LEDs)

For each of 3 LEDs (Rows 55, 56, 57):
1. Insert 1.5k resistor from (+) rail to the row.
2. Insert LED: anode (long leg) to the resistor output, cathode (short leg/flat)
   toward Q1.
3. Wire cathode to Q1 collector (Row 40 col D).

### Step 15: Twinkle Bank 1 (3 LEDs)

For each of 3 LEDs (Rows 58, 59, 60):
1. Wire from Q2 collector (Row 45 col D) to the LED anode (long leg).
2. Insert LED: cathode (short leg) toward the resistor.
3. Insert 2.2k resistor from LED cathode to (-) rail.

### Step 16: Twinkle Bank 2 (3 LEDs)

For each of 3 LEDs (Rows 61, 62, 63):
1. Wire from Q3 collector (Row 50 col D) to the LED anode.
2. Insert LED: cathode toward the resistor.
3. Insert 2.2k resistor from LED cathode to (-) rail.

### Verify Phase 7

- In room light (LDR exposed): **all 9 LEDs should be OFF**.
  If any glow, check wiring — likely a PNP emitter/collector swap.
- Cover LDR with dark cloth. Within seconds:
  - Twinkle LEDs should begin blinking in two independent patterns.
  - Steady LEDs should slowly fade in over ~30–60 seconds.
- Uncover LDR: all LEDs should turn off within a few seconds.

---

## Phase 8 — Final Tuning

### Step 17: Dusk Sensitivity

1. Simulate twilight by partially covering the LDR.
2. Adjust the dusk trimpot (RV1) until the circuit activates at your desired
   ambient light level.
3. The Schmitt hysteresis provides a ~1.2V dead band, so the on/off points will
   differ slightly — this is correct and prevents flicker.

### Step 18: Shimmer Character

1. Cover LDR fully and observe the twinkle pattern.
2. Adjust RV2 (Oscillator 1 speed) and RV3 (Oscillator 2 speed).
3. For best shimmer: set the two rates close but not equal. The beat frequency
   (difference) creates the drift pattern:
   - Very close rates → slow, subtle drift (recommended)
   - Far apart → fast, complex pattern
   - Identical → synchronized flashing (avoid)

### Step 19: Brightness (optional)

If LEDs are too dim or too bright, swap resistor values:

| Change | Swap To | New Current |
|---|---|---|
| Brighter steady | 680 ohm | ~2.1 mA |
| Dimmer steady | 3.3k | ~0.42 mA |
| Brighter twinkle | 1k | ~1.4 mA |
| Dimmer twinkle | 4.7k | ~0.30 mA |

### Step 20: Solar Integration

1. Connect solar panels (parallel: all + together, all - together).
2. Place panels near a window or under a desk lamp.
3. Verify charging: measure voltage at Row 3 (after diode) — should exceed
   battery voltage by at least 0.5V when panels are illuminated.
4. Leave running overnight to confirm auto-activation at dusk.

---

## Troubleshooting

| Symptom | Likely Cause | Fix |
|---|---|-----|
| All LEDs always ON | DARK stuck HIGH; LDR disconnected or wrong | Check LDR wiring; adjust dusk trimpot |
| LEDs never turn on | DARK stuck LOW; battery dead | Check battery voltage (>3.0V); check Pin 3 while covering LDR |
| Steady LEDs on but no twinkle | Oscillators not running | Probe Pin 4/10 for square wave; check 0.47uF caps and 1M resistors |
| Twinkle on during daylight | PNP wired backwards (E/C swapped) | Verify Q2/Q3 emitters go to (+) rail, not (-) |
| Steady LEDs snap on (no fade) | Fade cap shorted, wrong polarity, or missing | Check 100uF polarity; verify 470k fade resistor |
| IC gets hot | Floating input on Gate 4 | Verify Pin 12 and Pin 13 tied to (+) rail |
| Very dim LEDs | Low battery or wrong LED color (white/blue) | Charge battery; use red/amber LEDs (Vf ~2.0V) |
| One LED bank dimmer than others | Resistor value wrong | Measure each resistor before inserting |
| Oscillators at same rate | Trimpots at identical positions | Adjust RV2/RV3 to different settings |
| Solar not charging | Panels too low voltage or reversed | Verify 5.5V panels; check diode orientation (band toward battery) |

---

## Current Draw Quick-Check

Use your multimeter in series with the battery (+) lead:

| Condition | Expected |
|---|---|
| Daylight (LDR exposed) | < 0.05 mA (essentially zero) |
| Darkness (all LEDs active) | 4–7 mA (depends on instantaneous oscillator state) |
| Darkness (average over 30s) | ~5.1 mA |

If daylight draw exceeds 0.5 mA, a transistor is leaking — check Q2/Q3 PNP wiring.

---

## Next Steps After Prototyping

1. **Run for 24 hours** — verify day/night cycling, solar charging, and battery health.
2. **Transfer to perfboard** — solder all connections for permanent installation.
   Use a DIP-14 socket for the CD4093 so it can be replaced.
3. **Scatter LEDs** — extend LED leads with thin wire to position them throughout
   your "mine" enclosure. Randomness in placement adds to the organic feel.
4. **Seal the LDR** — if the installation is humid, coat the LDR with clear nail
   polish or epoxy to prevent moisture degradation.

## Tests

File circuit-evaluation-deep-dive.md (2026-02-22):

# Deep-Dive Circuit Evaluation — Diamond Mine Shimmer

## Scope

This evaluation is a design-review history of the Diamond Mine Shimmer Circuit. It
documents two critical flaws found in the original v1 design, the corrections applied,
and a forward-looking longevity analysis for the final corrected circuit. All critical
flaws described below have been **resolved** in the current design files.

---

## Executive Summary

| Category | Verdict |
|---|---|
| Analog shimmer concept | Excellent — dual beat-frequency oscillators are elegant and organic |
| Dusk detection + fade-in | Solid — Schmitt hysteresis and 47-second RC ramp work well |
| LED current design | Good — per-LED resistors, red/amber Vf match, low current |
| Solar charging | **RESOLVED** — upgraded to 5.5V panels with 10-ohm current limiter |
| Daytime LED gating | **RESOLVED** — PNP high-side switches ensure zero daytime LED current |
| NiMH longevity | Needs attention — no over-discharge cutoff, no charge regulation |
| Component lifetime | Good for 5–10 years with battery replacement every 2–3 years |

---

## Historical Flaw 1: Solar Panels Cannot Charge the Battery (RESOLVED)

> **Status: FIXED.** The current design uses 5.5V panels with a 10-ohm current-limiting resistor.

### The Original Problem

The BOM specifies **"~2V, 50–100 mA" solar panels wired in parallel**.

Parallel wiring preserves voltage and sums current. So 2–4 panels in parallel
produce **2V** at 100–400 mA.

The battery pack is **3x AA NiMH in series = 3.6V nominal** (range: 3.0V discharged
to 4.35V fully charged).

**A 2V source cannot push current into a 3.6V battery.** This is a fundamental
voltage mismatch. The Schottky diode is reverse-biased at all times — zero charging
current flows, ever.

```
Required:  V_solar > V_battery + V_diode
           V_solar > 4.35V + 0.3V = 4.65V  (worst case, fully charged)
           V_solar > 3.0V + 0.3V  = 3.3V   (best case, fully discharged)

Actual:    V_solar = 2.0V  (open circuit, parallel panels)

Result:    2.0V < 3.3V → NO CHARGING UNDER ANY CONDITION
```

### Why the Original Design Notes Seemed Plausible

The DESIGN-NOTES.md calculates "daily charge: ~100 mA x 4 hrs = 400 mAh" — but this
assumes the current actually flows. With a 2V source and 3.6V battery, the diode is
reverse-biased and **zero milliamps** flow regardless of panel current rating.

### The Fix

**Option A (recommended): Use higher-voltage panels**

Replace the 2V panels with **5V–6V solar panels** (common in NiMH garden-light
applications). Wire them in parallel for current:

```
2–3 panels rated 5.5V / 80–100 mA each, in parallel
→ 5.5V at 160–300 mA combined
→ After Schottky: 5.2V
→ Charges 3.6V NiMH pack comfortably
```

Add a **current-limiting resistor** (R_charge) in series to keep trickle rate safe:

```
R_charge = (V_panel - V_battery_max - V_diode) / I_target
         = (5.5 - 4.35 - 0.3) / 0.1
         = 8.5 ohm → use 10 ohm, 1/2W

At minimum battery voltage (3.0V):
  I = (5.5 - 3.0 - 0.3) / 10 = 220 mA  (C/9 — acceptable for NiMH)

At maximum battery voltage (4.35V):
  I = (5.5 - 4.35 - 0.3) / 10 = 85 mA   (C/24 — safe indefinite trickle)
```

**Option B: Wire three 2V panels in series**

```
3 panels in series: 6.0V at 50–100 mA per panel
After Schottky: 5.7V
```

This works but reduces available current to the weakest panel (series = current-limited
by the dimmest panel). Also 5.7V is high enough to need the current-limiting resistor.

**Option C: Use two pairs in series-parallel**

```
4 panels total:
  Panel 1 + Panel 2 in series = 4.0V
  Panel 3 + Panel 4 in series = 4.0V
  Two series strings in parallel = 4.0V at 2x current

After Schottky: 3.7V
```

This barely works when the battery is below 3.4V but fails to charge above that. Not
recommended — too little headroom.

### Updated BOM Entry

```
| 2–3 | Solar panels (5.5V) | 5–6V, 80–100 mA | Wired in parallel. Indoor-rated. |
| 1   | R_charge             | 10 ohm, 1/2W     | Series current limiter (solar → diode) |
```

---

## Historical Flaw 2: NAND Gating Bug — Twinkle LEDs ON During Daytime (RESOLVED)

> **Status: FIXED.** The current design uses PNP 2N3906 high-side drivers for Q2/Q3.

### The Original Problem

The corrected design gates the oscillators by feeding DARK to one input of each
NAND gate. The intent was to disable oscillation (and LED current) during daylight.

**NAND gate truth table:**

| DARK (Pin 5/8) | RC Node (Pin 6/9) | Output (Pin 4/10) |
|:-:|:-:|:-:|
| 0 (day) | 0 | **1** |
| 0 (day) | 1 | **1** |
| 1 (night) | 0 | 1 |
| 1 (night) | 1 | 0 |

When DARK = LOW (daytime), the output is **stuck HIGH** regardless of the RC node.

The output (Pin 4 / Pin 10) connects through 220k to the base of Q2 / Q3 (NPN):

```
Ib = (V_out - Vbe) / 220k = (3.6 - 0.7) / 220,000 = 13.2 uA
```

With hFE ~100 (typical for 2N3904 at low Ic):

```
Ic = hFE x Ib = 100 x 13.2 uA = 1.32 mA
```

Three LEDs per bank at 0.64 mA each = 1.92 mA needed. Q2/Q3 can supply ~1.3 mA —
enough to visibly illuminate the LEDs (dimmer than night mode, but clearly ON).

**Daytime current through twinkle LEDs:**

```
Twinkle Bank 1:  ~1.3 mA (constant, not oscillating)
Twinkle Bank 2:  ~1.3 mA (constant, not oscillating)
Base drive:       2 x 13 uA = 0.03 mA
─────────────────────────────────────
Total wasted:    ~2.6 mA during the day
```

This is **worse** than the original ungated oscillators (Issue 4), which at least had
50% duty cycle (~1.9 mA average). The "fix" made the problem larger.

The circuit-evaluation.md states "Zero LED current" during daytime — this is
**incorrect** for NPN common-emitter drivers fed by NAND-gate-stuck-HIGH.

### The Fix

**Option A (simplest, no extra parts): Switch Q2 and Q3 to PNP high-side drivers**

Replace the 2N3904 NPN transistors for Q2 and Q3 with **2N3906 PNP** transistors
wired as high-side switches:

```
                       VDD
                        │
                    Q2 Emitter (PNP 2N3906)
                        │
                    Q2 Collector
                        │
                       LED (anode)
                        │
                       LED (cathode)
                        │
                      2.2k
                        │
                       GND

Pin 4 (OSC1) ── 100k ── Q2 Base
```

PNP behavior:
- Base HIGH (≈ VDD) → Vbe ≈ 0 → PNP OFF → LEDs OFF
- Base LOW (≈ 0V) → Vbe ≈ -VDD → PNP ON → LEDs ON

Day: Output stuck HIGH → Q2 base ≈ VDD → PNP OFF → **LEDs OFF** (correct!)
Night: Output oscillates HIGH/LOW → LEDs blink ON/OFF (correct!)

LED current is identical:

```
I = (VDD - Vce_sat - Vf_LED) / R = (3.6 - 0.2 - 2.0) / 2200 = 0.64 mA
```

**BOM change:** Replace 2x 2N3904 (Q2, Q3) with 2x 2N3906. Same price, same package.
Q1 (steady bank) stays as 2N3904 NPN since it's controlled by the FADE ramp (0V
during day = already OFF).

**Option B: Add a common ground-path enable transistor (Q4)**

Keep Q2/Q3 as NPN but add a fourth transistor (Q4, 2N3904) in the shared emitter
return path:

```
Q2 Emitter ──┬── Q4 Collector
Q3 Emitter ──┘
                  Q4 Base ← 47k ← DARK (Pin 3)
                  Q4 Emitter → GND
```

Day:  DARK = LOW → Q4 OFF → Q2/Q3 emitters floating → no LED current
Night: DARK = HIGH → Q4 ON → Q2/Q3 emitters at ~0.2V → normal operation

Penalty: Extra Vce_sat (~0.2V) in series → LED current drops to:

```
I = (3.6 - 2.0 - 0.2 - 0.2) / 2200 = 0.55 mA  (14% dimmer)
```

**BOM change:** +1x 2N3904, +1x 47k resistor.

**Option C: Use Gate 4 to invert one oscillator output**

Rewire Gate 4 as an inverter on the Osc 1 output:

```
Pin 12 = Pin 4 (Osc 1 output)
Pin 13 = Pin 4 (tied together = inverter mode)
Pin 11 = inverted Osc 1 output → 220k → Q2 base
```

Day: Pin 4 stuck HIGH → Pin 11 LOW → Q2 OFF (correct!)
Night: Pin 4 oscillates → Pin 11 oscillates (inverted) → Q2 blinks (correct!)

Problem: Only fixes ONE oscillator. Gate 3 (Osc 2, Pin 10 → Q3) still has the
stuck-HIGH bug. No spare gate for a second inversion.

**Recommendation: Option A (PNP) is cleanest.** No extra parts, no voltage penalty,
fixes both banks.

---

## Power Budget — Recalculated

### Daytime (Standby) — With Both Fixes Applied

| Component | Current |
|---|---|
| CD4093 quiescent (static, no oscillation) | ~0.005 uA |
| LDR divider (bright: LDR ~5k, pull-down ~500k) | ~7 uA |
| Pin 3 LOW, FADE cap discharged, Q1 OFF | 0 |
| Pin 4/10 HIGH, PNP Q2/Q3 OFF | 0 |
| **Total standby** | **~7 uA** |

At 7 uA, the battery would last 2000 mAh / 0.007 mA = **285,000 hours** (~32 years)
on standby alone. Daytime draw is negligible.

### Nighttime (Active) — Corrected Component Values

| Component | Current | Notes |
|---|---|---|
| CD4093 + oscillators (dynamic) | ~0.1 mA | Two gates oscillating at ~2.5 Hz |
| LDR divider (dark: LDR ~1M, pull-down ~500k) | ~2.4 uA | Negligible |
| Q1 base drive (FADE/10k) | ~0.29 mA | At full FADE voltage |
| Q2/Q3 base drive (2 x 29 uA) | ~0.06 mA | Through 100k each |
| Steady Bank: 3 LEDs x 0.93 mA | 2.79 mA | Through 1.5k each |
| Twinkle Bank 1: 3 LEDs x 0.64 mA x 50% duty | 0.96 mA | Square wave, 50% avg |
| Twinkle Bank 2: 3 LEDs x 0.64 mA x 50% duty | 0.96 mA | Square wave, 50% avg |
| **Total active (average)** | **~5.1 mA** | |
| **Total active (peak, all on)** | **~7.0 mA** | |

### Battery Life Without Solar

```
Continuous darkness: 2000 mAh / 5.1 mA = 392 hours ≈ 16.3 days
10 hrs/night cycle:  392 / 10 = ~39 nights
14 hrs/night (winter): 392 / 14 = ~28 nights
```

### Solar Energy Balance (with corrected 5.5V panels)

```
Solar input (2 panels, 100 mA combined, 4 hrs effective indoor light):
  Daily charge = 100 mA x 4 hrs = 400 mAh

Nighttime consumption (10 hrs):
  Daily discharge = 5.1 mA x 10 hrs = 51 mAh

Net daily surplus = +349 mAh → Battery stays full indefinitely

Even worst case (1 panel, dim window, 2 hrs effective):
  Daily charge = 50 mA x 2 hrs = 100 mAh
  Daily discharge = 51 mAh
  Net surplus = +49 mAh → Still self-sustaining
```

### Break-Even Analysis

Minimum solar input to sustain the circuit:

```
Required:  I_solar x t_sun  >=  I_active x t_night
           I_solar x t_sun  >=  5.1 mA x 10 hrs = 51 mAh

With 2 panels (100 mA combined):
  Minimum effective sun = 51 / 100 = 0.51 hours (31 minutes)

With 1 panel (50 mA):
  Minimum effective sun = 51 / 50 = 1.02 hours (61 minutes)
```

Even one hour of decent indoor light per day is enough. The design has excellent
solar margin.

---

## Longevity Analysis

### NiMH Battery Lifecycle

| Factor | Value | Impact |
|---|---|---|
| Cycle life | 500–1000 cycles (Eneloop: 2100) | At 1 cycle/day: **1.4–5.8 years** |
| Self-discharge | Standard: 1–5%/day; Eneloop: ~15%/6 months | Use low-self-discharge cells |
| Voltage per cell at end-of-life | Drops from 1.2V to ~1.0V nominal | Circuit still runs (3.0V > CD4093 minimum) |
| Over-discharge damage threshold | Below 1.0V/cell (3.0V pack) | See protection discussion below |
| Temperature sensitivity | Loses 20–40% capacity below 0C | Indoor installation avoids this |
| Memory effect | Minimal with NiMH (unlike NiCd) | Not a concern |

**Recommendation:** Use **Eneloop or Eneloop Pro** cells. Their 2100-cycle rating at
1 cycle/day gives **5.8 years** before capacity drops below 80%. Plan for battery
replacement every 3–5 years as part of installation maintenance.

### Over-Discharge Protection

The corrected design notes (Issue 8) acknowledge this gap. NiMH cells are damaged
when discharged below 1.0V/cell (3.0V for the pack). The CD4093 stops functioning
cleanly below ~3V, providing a rough natural cutoff — but it's imprecise.

**During the transition zone (3.0–3.3V):**
- CD4093 oscillators may become erratic
- LED brightness drops significantly (Vdd - Vf headroom shrinks)
- The dusk detector threshold shifts (Schmitt thresholds are proportional to VDD)

**Low-cost protection options:**

1. **Zener voltage monitor (simplest):** Add a 3.0V zener diode + 100k resistor from
   VDD to the DARK signal path. When VDD drops below ~3.2V, the zener stops conducting
   and pulls the DARK line low via a divider — disabling all LEDs.

2. **Voltage supervisor IC:** A TL431 or MAX809 (costs ~$0.50) provides a clean
   under-voltage lockout at a precise threshold.

3. **Accept the natural cutoff:** The CD4093's graceful degradation below 3V effectively
   shuts down the LEDs. NiMH cells can tolerate occasional shallow over-discharge.
   For an art installation checked periodically, this may be acceptable.

### Charge Regulation

With the recommended 10-ohm current-limiting resistor and 5.5V panels:

| Condition | Charge Current | Rate |
|---|---|---|
| Battery at 3.0V (discharged) | ~220 mA | C/9 |
| Battery at 3.6V (nominal) | ~160 mA | C/12.5 |
| Battery at 4.35V (full) | ~85 mA | C/24 |

NiMH cells safely tolerate continuous charge at C/10 or below. The 220 mA peak
(C/9) at deeply discharged state is slightly above C/10 but occurs only briefly.
The self-tapering characteristic of the resistor (higher battery voltage = lower
current) provides crude but effective regulation.

For extra safety, increase R_charge to **15 ohm** (limits peak to ~147 mA = C/14).

### Component Lifetime Estimates

| Component | Expected Life | Failure Mode | Notes |
|---|---|---|---|
| CD4093 CMOS IC | 20+ years | Latch-up, ESD | Essentially indefinite at room temp |
| 2N3904 / 2N3906 | 20+ years | None expected | Solid-state, no wear mechanism |
| 1N5819 Schottky | 15+ years | Increased Vf | Minimal degradation |
| Film capacitors (0.47uF) | 20+ years | None expected | Excellent long-term stability |
| Electrolytic cap (100uF) | 10–15 years | Dry-out, ESR rise | Replace at 10-year mark |
| LDR (GL5528, CdS) | 5–10 years | Sensitivity drift | CdS degrades with UV and humidity |
| NiMH batteries | 3–5 years | Capacity fade | Replace when runtime noticeably drops |
| Trimpots | 10+ years | Wiper wear (rare) | Set-and-forget, minimal wear |
| Breadboard contacts | 2–5 years | Intermittent connections | Transfer to perfboard for permanence |

**Key maintenance schedule for a permanent installation:**

| Interval | Action |
|---|---|
| Year 1 | Check battery voltage, re-tune trimpots if needed |
| Year 2–3 | Replace NiMH cells (standard) or check (Eneloop) |
| Year 3–5 | Replace NiMH cells (Eneloop), inspect solder joints |
| Year 5 | Transfer from breadboard to perfboard if not already done |
| Year 5–10 | Replace LDR if dusk sensitivity has drifted |
| Year 10 | Replace electrolytic capacitor (100uF) |

---

## What Works Well — Design Strengths

### 1. Dual Beat-Frequency Shimmer (Excellent)

The two oscillators at slightly different frequencies (~2.4 Hz and ~2.6 Hz) create a
beat pattern with period ≈ 1/(2.6-2.4) = 5 seconds. This produces a slowly drifting
shimmer that never exactly repeats — far more organic than a single blink rate or any
digital PWM pattern.

The 100k trimpots give fine control over the frequency offset, allowing the installer
to tune the "personality" of the shimmer from quick sparkle to slow breathing.

### 2. Schmitt-Trigger Dusk Detection (Solid)

The CD4093's built-in hysteresis (~30% of VDD = ~1.08V band at 3.6V) prevents
rapid on/off cycling during gradual twilight transitions. This is a textbook
application of Schmitt-trigger logic and works reliably.

The three-element pull-down (470k + 100k trimpot || 47k) provides:
- A fixed baseline threshold (470k + 47k = 517k minimum)
- Fine adjustment via trimpot (470k + 32k = 502k maximum)
- The adjustment range is narrow (~3%), which means the trimpot acts as a
  sensitivity fine-tune rather than a coarse control. This is appropriate for
  a set-once installation.

### 3. Fade-In Ramp (Well-Designed)

The 470k + 100uF RC network (tau = 47 seconds) creates a natural exponential bloom:

| Time | Voltage | Perceived Brightness |
|---|---|---|
| 0s | 0V | Dark |
| 10s | 0.7V | First visible glow (Vbe threshold) |
| 25s | 1.5V | Moderate |
| 47s | 2.3V | ~63% (one time constant) |
| 90s | 3.1V | ~86% |
| 141s | 3.4V | ~95% (effectively full) |

The Q1 transistor operates in its linear (active) region during the ramp, so LED
current rises smoothly rather than snapping on. The visual effect is an organic
"bloom" that feels like bioluminescence waking up.

At dawn (DARK goes LOW), the capacitor discharges through the 10k base resistor
(tau = 10k x 100uF = 1 second) while Q1 is conducting, then slowly through 470k
after Q1 turns off. The LEDs fade out in ~2–3 seconds — a fast but not jarring
transition.

### 4. Per-LED Current Limiting (Correct Practice)

Individual resistors per LED (1.5k for steady, 2.2k for twinkle) ensure equal
current sharing despite LED manufacturing Vf variations. This is essential for
visual uniformity in the "diamond field" and prevents one LED from hogging current
while others go dark.

### 5. Component Selection (Appropriate)

- **CD4093 CMOS** — runs from 3–18V with nanoamp quiescent current. Perfect for
  battery operation.
- **1N5819 Schottky** — 0.3V drop vs 0.6V for silicon. At 3.6V supply, this saves
  8% of the rail voltage — significant.
- **Film capacitors for oscillators** — tight tolerance, zero piezo effect, stable
  over temperature and time. Critical for consistent twinkle rates.
- **Red/amber LEDs (Vf 1.8–2.1V)** — correct choice for 3.6V supply. White/blue
  LEDs (Vf 3.0–3.2V) would leave almost no headroom and be extremely dim.

### 6. Ultra-Low Standby Power (with fixes applied)

At ~7 uA standby, the circuit essentially disappears from the battery's perspective
during daylight. This means 100% of solar energy goes to charging, with no parasitic
drain fighting the panels.

---

## Minor Issues and Recommendations

### 1. Breadboard Is Not Permanent

Solderless breadboard contacts degrade over time (oxidation, vibration, thermal
cycling). For an art installation meant to run for years:

**Recommendation:** Prototype on breadboard, then transfer to perfboard or stripboard
with soldered connections. Use a DIP socket for the CD4093 to allow replacement.

### 2. No Power Switch

Fine for a permanent installation, but makes debugging difficult. Adding an SPST
toggle between battery+ and VDD costs nothing and saves hours of troubleshooting.

### 3. Twinkle Banks Lack Fade-In

The steady bank fades in beautifully via the RC ramp, but the twinkle banks switch
on abruptly once the DARK signal enables the oscillators. This is acceptable
aesthetically — the "sparkle emerging from darkness" effect works — but for maximum
polish, you could:

- Route the oscillator outputs through resistors to the FADE node via diodes (OR
  gate), so twinkle brightness also tracks the fade ramp
- Or accept the abrupt onset as a deliberate design choice (diamonds "appearing")

### 4. Environmental Concerns (CdS LDR)

The GL5528 LDR contains cadmium sulfide, which is restricted under RoHS in some
jurisdictions. For a personal art project this is fine, but be aware:

- Dispose of responsibly (electronic waste, not household trash)
- If the installation is in a humid environment, seal the LDR or replace with a
  phototransistor (e.g., TEPT5700) and adjust the divider resistors accordingly

### 5. Oscillator Frequency Range Is Narrow

With 1M fixed + 100k trimpot, the adjustable range is only 2.4–2.6 Hz (an 8% span).
The beat frequency varies from 0 to 0.2 Hz — a range of "perfectly in sync" to
"5-second drift cycle."

For more dramatic shimmer variation, consider:
- Increase trimpots to **500k** → range becomes 1.3–2.6 Hz
- Or use different fixed resistors for each oscillator (e.g., 1M and 680k) to
  guarantee a permanent frequency offset even with trimpots centered

### 6. Gate 4 Could Add a Third Shimmer Layer

Gate 4 is currently wasted (inputs tied to VDD). It could be wired as a third
oscillator at a very different rate:

- **Slow breathing (0.2 Hz):** 1M + 2.2uF → drives a fourth LED group through
  another PNP transistor. Creates a "breathing" underlayer.
- **Fast glitter (8–10 Hz):** 220k + 0.47uF → drives a small LED cluster. Creates
  a subtle high-speed sparkle overlay.

This would add one more layer to the visual complexity at the cost of one transistor,
a few resistors, and some LEDs.

---

## Discrepancies Between Documents

The original BUILD-GUIDE.md has several conflicts with the corrected design:

| BUILD-GUIDE.md Says | Corrected Design Says | Issue |
|---|---|---|
| Step 5: Gate 4 pins 12+13 tied to **GND** | Pins 12+13 tied to **VDD** | Both work, but VDD is conventional (output LOW = lower power) |
| Step 10: Pins 4+5 tied (inverter mode) | Pin 5 = DARK gating input | Different oscillator topology |
| Steps 14–15: 47k base resistors | 100k base resistors | 47k gives ~62 uA Ib (original), 100k gives ~29 uA (corrected) |
| Step 10: Pin 6 = output (2Y) | Pin 4 = output (2Y) | The corrected schematic matches the actual CD4093 datasheet (TI) |
| BOM.md: Gate 2 = pins 4,5 → 6 | Corrected: Gate 2 = pins 5,6 → 4 | Original BOM had pin assignments backwards |

The corrected documents are authoritative. The BUILD-GUIDE.md should be updated to
match.

---

## Summary of Changes

### Critical Fixes (applied — circuit now functions correctly)

| # | Issue | Fix Applied | BOM Impact |
|---|---|---|---|
| **F1** | Solar panels (2V) cannot charge 3.6V battery | Replaced with 5.5V panels; added 10-ohm series resistor | Changed panel spec, +1 resistor |
| **F2** | NAND stuck-HIGH turns twinkle LEDs ON during day | Replaced Q2, Q3 with 2N3906 PNP high-side switches; base drive set to 100k for reliable saturation | Changed 2x 2N3904 → 2x 2N3906 |

### Recommended for Longevity

| # | Issue | Recommendation | BOM Impact |
|---|---|---|---|
| **S1** | No NiMH over-discharge protection | Accept natural CD4093 cutoff at ~3V, or add voltage supervisor | Optional: +1 IC ($0.50) |
| **S2** | Breadboard not permanent | Transfer to perfboard after prototyping | Perfboard + solder |
| **S3** | No power switch | Add SPST toggle on VDD line | +1 switch ($0.50) |

### Nice to Have (enhanced experience)

| # | Issue | Fix |
|---|---|-----|
| **N1** | Narrow oscillator frequency range | Use 500k trimpots or different fixed resistors per oscillator |
| **N2** | Gate 4 wasted | Wire as third oscillator for breathing or glitter layer |
| **N3** | Twinkle banks lack fade-in | Add diode-OR from oscillators through FADE node (complex) |

---

## Updated BOM Delta (changes from corrected BOM)

```diff
  ## Power
- | 2–4 | Small solar panels | ~2V, 50–100 mA each. Wired in parallel. Indoor-rated. |
+ | 2–3 | Solar panels (5.5V) | 5–6V, 80–100 mA each. Wired in parallel. Indoor-rated. |
+ | 1   | Resistor (R_charge) | 10–15 ohm, 1/2W. Series current limiter in solar charge path. |

  ## Active Components
  (Q2 and Q3 change)
- | 3 | 2N3904 | TO-92 | NPN general-purpose transistor (Q1, Q2, Q3). |
+ | 1 | 2N3904 | TO-92 | NPN general-purpose transistor (Q1 — steady bank). |
+ | 2 | 2N3906 | TO-92 | PNP general-purpose transistor (Q2, Q3 — twinkle banks). |
```

### Revised Twinkle LED Wiring (PNP High-Side)

```
              VDD (+3.6V)
                │
         Q2 Emitter (2N3906 PNP)
                │
         Q2 Collector
           ┌────┼────┐
           │    │    │
          LED  LED  LED   (anodes)
           │    │    │
          LED  LED  LED   (cathodes)
           │    │    │
         2.2k  2.2k 2.2k
           │    │    │
           └────┼────┘
                │
               GND

Pin 4 (OSC1) ── 100k ── Q2 Base

Day:   Pin 4 = HIGH → Q2 base ≈ VDD → Veb ≈ 0 → OFF → LEDs dark
Night: Pin 4 oscillates → Q2 toggles → LEDs shimmer
```

---
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

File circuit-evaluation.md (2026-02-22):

# Circuit Evaluation — Diamond Mine Shimmer

## Design Summary

Single CD4093 Schmitt-trigger NAND IC provides dusk detection (Gate 1) and two
gated oscillators (Gates 2 and 3). Solar panels charge NiMH batteries through a
Schottky diode with resistive current limiting. At dusk, an LDR triggers the
circuit: the steady LED bank fades in via an RC ramp through an NPN driver (Q1),
while two twinkle banks shimmer through PNP high-side drivers (Q2, Q3) toggled by
the gated oscillators. At dawn, the oscillators hold HIGH, PNP drivers turn OFF,
and the fade cap discharges — all LEDs go dark and standby draw falls to ~7 uA.

---

## Strengths

- **Dusk detector** — LDR voltage divider with Schmitt hysteresis (Gate 1 in inverter
  mode). Clean switching, no twilight flicker. ~1.08V hysteresis band at 3.6V VDD.

- **Fade-in ramp** — 470k + 100uF (τ = 47s). LEDs begin glowing at ~10 seconds, full
  brightness around 40 seconds. Organic bloom effect.

- **Dual non-synchronized oscillators** — Two square waves at slightly different
  frequencies (~2.4 Hz and ~2.6 Hz) create beat patterns with ~5-second drift cycles
  that never mechanically repeat.

- **PNP high-side twinkle switches** — NAND outputs go HIGH when DARK is LOW (day).
  PNP transistors (2N3906) are OFF when base ≈ VDD. This ensures **zero twinkle LED
  current during daylight** — a requirement for net-positive solar charging.

- **NPN low-side steady switch** — Q1 driven by FADE ramp (0V during day) naturally
  stays OFF. Provides smooth linear brightness control during nighttime fade-in.

- **Current-limited solar charging** — R_charge (10 ohm) self-tapers the charge rate:
  220 mA at 3.0V battery (C/9) down to 85 mA at 4.35V (C/24). Safe for NiMH
  indefinite trickle with no charge controller required.

- **Per-LED current limiting** — Individual resistors ensure equal brightness across
  all LEDs despite manufacturing Vf variation.

- **1N5819 Schottky** — 0.3V drop vs 0.6V for silicon. Preserves millivolts at 3.6V.

---

## Current Draw Summary

```mermaid
pie title Active Current Budget (~5.1 mA average)
    "Steady Bank (3 LEDs @ 0.93 mA)" : 2.79
    "Twinkle Bank 1 (3 LEDs @ 0.64 mA, 50%)" : 0.96
    "Twinkle Bank 2 (3 LEDs @ 0.64 mA, 50%)" : 0.96
    "Q1 base drive" : 0.29
    "CD4093 dynamic + base drives" : 0.16
```

| State | Current | Battery Life (2000 mAh) |
|---|---|---|
| Daylight (standby) | ~7 uA | ~32 years (effectively infinite) |
| Darkness (all LEDs, average) | ~5.1 mA | ~390 hours (~16 days) |
| Darkness (peak, all on) | ~7.0 mA | ~285 hours (~12 days) |

---

## Solar Energy Balance

| Parameter | Value |
|---|---|
| Solar panels | 2x 5.5V, 100 mA each, parallel |
| Daily charge (4 hrs effective sun) | 200 mA × 4 hrs = 800 mAh |
| Daily discharge (10 hrs night) | 5.1 mA × 10 hrs = 51 mAh |
| **Net daily surplus** | **+749 mAh** |
| Minimum sun to sustain | 0.26 hrs (16 min) with 2 panels |

The circuit is easily solar self-sustaining with even modest indoor light.

---

## Daytime Behavior

| Component | State | Current |
|---|---|---|
| LDR divider | SENSE ≈ VDD → Gate 1 output LOW | ~7 uA |
| Gate 1 output (DARK) | LOW | — |
| Fade ramp (100uF) | Discharged (0V) | 0 |
| Q1 (NPN) | OFF (base = 0V) | 0 |
| Gate 2 output (Pin 4) | Stuck HIGH | — |
| Gate 3 output (Pin 10) | Stuck HIGH | — |
| Q2 (PNP) | OFF (base ≈ VDD, Veb ≈ 0) | 0 |
| Q3 (PNP) | OFF (base ≈ VDD, Veb ≈ 0) | 0 |
| **Total standby** | | **~7 uA** |

---

## Nighttime Behavior

| Component | State | Current |
|---|---|---|
| LDR divider | SENSE ≈ low → Gate 1 output HIGH | ~2.4 uA |
| Gate 1 output (DARK) | HIGH | — |
| Fade ramp | Charges 0V → 3.6V over ~47s | — |
| Q1 (NPN) | ON (linear → saturated) | See LED bank |
| Gate 2 output | Oscillating ~2.6 Hz | ~50 uA |
| Gate 3 output | Oscillating ~2.4 Hz | ~50 uA |
| Q2 (PNP) | Toggling (50% duty) | See LED bank |
| Q3 (PNP) | Toggling (50% duty) | See LED bank |
| Steady LEDs (3x) | 0.93 mA each | 2.79 mA |
| Twinkle 1 LEDs (3x, 50%) | 0.64 mA each × 50% | 0.96 mA |
| Twinkle 2 LEDs (3x, 50%) | 0.64 mA each × 50% | 0.96 mA |
| Base drives | Q1: 0.29 mA, Q2/Q3: 0.029 mA each | 0.35 mA |
| **Total active (average)** | | **~5.1 mA** |

---

## Charge Current Profile

| Battery Voltage | Charge Current | Rate | Notes |
|---|---|---|---|
| 3.0V (discharged) | 220 mA | C/9 | Brief, acceptable |
| 3.6V (nominal) | 160 mA | C/12.5 | Normal operating point |
| 4.0V (near full) | 120 mA | C/17 | Safe |
| 4.35V (fully charged) | 85 mA | C/24 | Indefinite trickle safe |

---

## Known Limitations

| # | Item | Severity | Notes |
|---|---|---|---|
| 1 | No NiMH over-discharge cutoff | Minor | CD4093 degrades below ~3V, providing rough natural cutoff. For extra protection, add a voltage supervisor IC. |
| 2 | No power switch | Minor | Fine for permanent install. Add SPST toggle for debugging. |
| 3 | White/blue LEDs very dim | Info | Vf ~3.0V leaves only ~0.4V headroom. Use red/amber/yellow (Vf ~1.8–2.1V). |
| 4 | Breadboard not permanent | Info | Transfer to perfboard for installations lasting >1 year. |
| 5 | Twinkle banks lack fade-in | Aesthetic | They appear abruptly when oscillators start. Steady bank fades smoothly. |
| 6 | Narrow oscillator trim range | Info | 2.4–2.6 Hz (8% span). Use 500k trimpots for wider range. |

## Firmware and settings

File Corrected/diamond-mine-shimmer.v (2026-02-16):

// ===========================================================================
// Diamond Mine Shimmer Circuit — Verilog Behavioral Model
// ===========================================================================
//
// This is a behavioral (non-synthesizable) Verilog model of the Diamond Mine
// Shimmer Circuit. It models the digital logic of the CD4093 gates and the
// high-level analog behavior of the RC timing networks, dusk detector, and
// LED drivers.
//
// PURPOSE:
//   - Functional verification of the logic flow
//   - Timing visualization of oscillator beat patterns
//   - Day/night state machine verification
//
// LIMITATIONS:
//   - Analog voltages approximated with real-valued variables
//   - Schmitt hysteresis modeled with explicit thresholds, not feedback
//   - LED current not precisely modeled (on/off only)
//   - Solar charging not modeled (power assumed available)
//
// SIMULATOR: Icarus Verilog (iverilog) or any Verilog simulator
//   iverilog -o sim diamond-mine-shimmer.v && vvp sim
//
// ===========================================================================

`timescale 1ms / 1us

// ===========================================================================
// CD4093 Schmitt-Trigger NAND Gate — Behavioral
// ===========================================================================
module cd4093_gate (
    input  wire inA,
    input  wire inB,
    output reg  out,
    input  wire vdd_ok    // power good indicator
);
    // Propagation delay ~125ns at 3.6V (modeled as 1us for simulation scale)
    parameter TPROP = 1;  // microseconds (scaled to 1ms timescale = 0.001)

    always @(*) begin
        if (!vdd_ok) begin
            out = 1'b0;
        end else begin
            // NAND: output LOW only when both inputs HIGH
            #0 out = ~(inA & inB);
        end
    end
endmodule

// ===========================================================================
// Schmitt-Trigger Oscillator — Behavioral
// ===========================================================================
// Models a CD4093 relaxation oscillator with gating input.
// When gate_enable is LOW, output is stuck HIGH (NAND behavior).
// When gate_enable is HIGH, oscillates at approximately 1/(1.2*R*C).
//
module schmitt_oscillator #(
    parameter real R_OHM   = 1050000.0,  // Total R (1M + trimpot)
    parameter real C_FARAD = 0.00000047  // 0.47uF
)(
    input  wire gate_enable,  // DARK signal (HIGH = night = oscillate)
    output reg  osc_out,
    input  wire vdd_ok
);
    // Calculate period: T = 1.2 * R * C (in milliseconds for timescale)
    localparam real PERIOD_SEC = 1.2 * R_OHM * C_FARAD;
    // Convert to integer ms for delay (half-period for 50% duty)
    localparam integer HALF_PERIOD_MS = $rtoi(PERIOD_SEC * 500.0);

    initial osc_out = 1'b1;

    always begin
        if (!vdd_ok) begin
            osc_out = 1'b0;
            #1;
        end else if (!gate_enable) begin
            // NAND with one input LOW → output stuck HIGH
            osc_out = 1'b1;
            #1;
        end else begin
            // Oscillating: toggle at half-period intervals
            osc_out = ~osc_out;
            #(HALF_PERIOD_MS);
        end
    end
endmodule

// ===========================================================================
// Fade-In Ramp — Behavioral
// ===========================================================================
// Models the 470k + 100uF RC charge/discharge with 8-bit resolution.
// Output represents the FADE voltage as a fraction of VDD (0–255).
//
module fade_ramp #(
    parameter real TAU_SEC = 47.0  // R * C = 470k * 100uF
)(
    input  wire       dark,       // DARK signal (HIGH = charging)
    output reg  [7:0] fade_level, // 0–255 representing 0V to VDD
    input  wire       clk_1ms,    // 1 ms tick clock
    input  wire       vdd_ok
);
    real voltage;          // 0.0 to 1.0 (fraction of VDD)
    real step_charge;      // per-ms charge increment
    real step_discharge;   // per-ms discharge (through 10k, ~1s tau)

    initial begin
        voltage = 0.0;
        fade_level = 8'd0;
        // Charge step: delta_V per ms = (1/tau) * dt = (1/47000) * 1 = 0.0000213
        step_charge = 1.0 / (TAU_SEC * 1000.0);
        // Discharge step: 10k * 100uF = 1s tau → fast discharge while Q1 conducts
        step_discharge = 1.0 / (1.0 * 1000.0);
    end

    always @(posedge clk_1ms) begin
        if (!vdd_ok) begin
            voltage = 0.0;
        end else if (dark) begin
            // Exponential charge toward 1.0
            voltage = voltage + (1.0 - voltage) * step_charge * 1000.0 / TAU_SEC;
            if (voltage > 1.0) voltage = 1.0;
        end else begin
            // Discharge (fast through Q1 base path, then slow through 470k)
            if (voltage > 0.194) begin
                // Above Vbe/VDD threshold: fast discharge through 10k path
                voltage = voltage - voltage * step_discharge * 1000.0;
            end else begin
                // Below Vbe: slow discharge through 470k
                voltage = voltage - voltage * step_charge * 1000.0 / TAU_SEC;
            end
            if (voltage < 0.001) voltage = 0.0;
        end
        fade_level = $rtoi(voltage * 255.0);
    end
endmodule

// ===========================================================================
// Dusk Detector — Behavioral
// ===========================================================================
// Models the LDR voltage divider + Schmitt-trigger Gate 1.
// Input: ambient_light (0 = pitch dark, 255 = bright)
// Output: dark signal (HIGH when dark enough)
//
module dusk_detector (
    input  wire [7:0] ambient_light,  // 0=dark, 255=bright
    output reg        dark,
    input  wire       vdd_ok
);
    // Schmitt thresholds (as fraction of 255):
    //   VT+ ~ 0.66 * 255 = 168 (rising threshold, light increasing)
    //   VT- ~ 0.33 * 255 = 84  (falling threshold, light decreasing)
    // SENSE voltage is inversely proportional to light (LDR on high side)
    // So: SENSE high in bright → Gate 1 output LOW
    //     SENSE low in dark   → Gate 1 output HIGH

    parameter THRESH_DARK = 80;   // Below this → DARK goes HIGH
    parameter THRESH_LIGHT = 160; // Above this → DARK goes LOW

    initial dark = 1'b0;

    always @(*) begin
        if (!vdd_ok) begin
            dark = 1'b0;
        end else if (ambient_light < THRESH_DARK && !dark) begin
            dark = 1'b1;  // Just got dark enough
        end else if (ambient_light > THRESH_LIGHT && dark) begin
            dark = 1'b0;  // Just got bright enough
        end
        // Otherwise hold current state (hysteresis)
    end
endmodule
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

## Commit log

2026-02-16 Update design documentation and BOM for Diamond Mine Shimmer circuit. Enhanced clarity on component specifications, added current limiting details for solar charging, and refined circuit descriptions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
    [BOM.csv, bom.csv, diamond-mine-shimmer.kicad_pcb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]
2026-02-22 Add detailed assembly diagrams and images to documentation for Diamond Mine Shimmer circuit. Enhanced BUILD-GUIDE and README with visual references for breadboard layout, power section, IC connection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
    [BOM.csv, diamond-mine-shimmer.kicad_pcb]
